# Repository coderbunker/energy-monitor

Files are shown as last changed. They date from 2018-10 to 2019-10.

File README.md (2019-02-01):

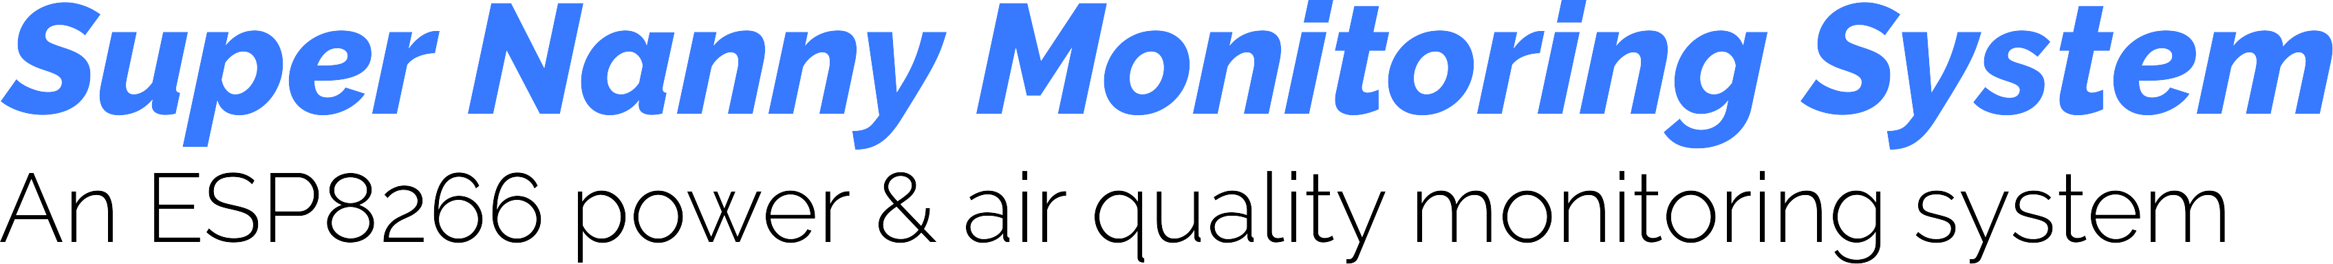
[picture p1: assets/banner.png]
Banner


*Super Nanny Monitory System* is a ESP6288 NodeMCU based monitoring system that measures power consumption and air quality. The MCU collects the data and sends it to the InfluxDB via UDP. 

This is the hardware/firmware repository which contains wiring images, mapping lists and other documentations.

**The Main Programm is [Writing_Database.ino](https://github.com/joelvonrotz/energy-monitor/blob/master/source/Writing_Database/Writing_Database.ino)**

## Measurements Types

The device is split into two devices: power measurement and air quality, so that means double the microcontroller is required instead of a single one.

The two devices can measure power consumption and the air quality as mentioned before. Air quality measurements contains:

- CO2
- TVOC
- Temperature
- Humidity

The power measurement contains the measured power consumption only.

## Setup Arduino

### Arduino IDE

Obviously to use the program in your own version you'd need the Arduino IDE. Simply download it from the Arduino website.
This code has been written with the Arduino language and maybe in the future other options could be available (STM, Atmel, NXP, etc.).

[Link to Arduino IDE](https://www.arduino.cc/en/Main/Software)

### Visual Studio Code Arduino Extension

Faster programmer can use the Arduino extension by Microsoft for Visual Studio Code. Before installing it, be sure to have the Arduino IDE installed, as the extension requires the IDE. It takes some workload off and adds some small nifty features to it.

[Link to extension](https://marketplace.visualstudio.com/items?itemName=vsciot-vscode.vscode-arduino)

### Libraries

To correctly use this program, some libraries need to be installed first. Below should all the needed libraries be listed.

- [InfluxDB-UDP Library](https://github.com/joelvonrotz/Arduino_InfluxDB_UDP) by joelvonrotz
- [Si7021 Library](https://github.com/sparkfun/Si7021_Breakout) by SparkFun
- [CCS811 Library](https://github.com/adafruit/Adafruit_CCS811) by Adafruit
- [ADS1X15 Library](https://github.com/adafruit/Adafruit_ADS1X15) by Adafruit
- [ESP8266 Hardware Package](https://github.com/esp8266/Arduino) by ESP8266.<span></span>com

## Mapping List

The mapping list is used to determine which controller goes into which building and room. First concept was to use a JSON-file in a GitHub repository, but since GitHub is HTTPS secured and using the HTTPS-protocol with the ESP8266 would take a lot of time to learn (time which wasn't available due to our 3-week stay in Shanghai). The problem with HTTPS is the temporary certificates, that lose useability due to their duration. That certificate would need to be refreshed every time the old one is done.

The solution was a hard-coded table, sadly. The MAC address of each ESP is used to get the different information in the table. The advantage of this system is, is that everything is kept offline instead stored in a cloud, which makes offline use kind of useable.

Below is the current mapping since 17th of October 2018.

|MAC Address |Location |Room |Type |
|:---|:---|:---|:---|
| B8:77:10:C2:DD:BC | Building 9  | Fuse box | Power Measurement |
| E8:42:69:3A:7D:80 | Coderbunker | artoffice | Power Measurement |
| FB:61:69:3A:7D:80 | Building 9  | Classroom | Air Quality |
| 49:7A:10:C2:DD:BC | Building 9  | Meeting Room Green | Air Quality |
| CD:36:69:3A:7D:80 | Coderbunker | Art Office | Air Quality |
| 3D:78:10:C2:DD:BC | Coderbunker | Kitchen | Air Quality |

Future people that are going to work on this, please keep this updated if new devices has been integrated into the system.

In the Arduino File called *Writing_Database.ino* is the mapping list and this is how it looks like:

```cpp
const String config[DEVICE_COUNT][TABLE_WIDTH]
{
    //MAC Address          location          room            type
    {"b8:77:10:c2:dd:bc", "building9",      "fusebox",      "power"     },
    {"44:39:69:3a:7d:80", "building1",      "dummy",        "power"     },
    {"e8:42:69:3a:7d:80", "coderbunker",    "artoffice",    "power"     },
    {"cd:36:69:3a:7d:80", "coderbunker",    "kitchen",      "quality"   },
    {"3d:78:10:c2:dd:bc", "coderbunker",    "artoffice",    "quality"   },
    {"fb:61:69:3a:7d:80", "coderbunker",    "classroom",    "quality"   },
    {"49:7a:10:c2:dd:bc", "coderbunker",    "meetingroom",  "quality"   },
    {"49:7a:10:c2:dd:bc", "coderbunker",    "meetingroom",  "quality"   }
};
```

### Add new MCU

To add new devices, it's actually very simple. First upload the program called *Get_MAC.ino* inside the *Get_MAC* folder and then the MAC-Address of the MCU should pop up in the Serial Monitor. Remember it!

Let's say the MAC-Address is ```13:57:91:AB:CD:EF```. Go back to the *Writing_Database.ino* program and increment the definition ```DEVICE_COUNT``` by one, for example from ```7``` to ```8```, so the compiler knows how big the new mapping list is.

If that has been made, let's add the device into the mapping list. Create a new empty package divided into 4 more sections, enough for the MAC-address, location, room and board type.

```cpp
const String config[DEVICE_COUNT][TABLE_WIDTH]
{
    //MAC Address          location          room            type
    {"b8:77:10:c2:dd:bc", "building9",      "fusebox",      "power"     },
    {"44:39:69:3a:7d:80", "building1",      "dummy",        "power"     },
    {"e8:42:69:3a:7d:80", "coderbunker",    "artoffice",    "power"     },
    {"cd:36:69:3a:7d:80", "coderbunker",    "kitchen",      "quality"   },
    {"3d:78:10:c2:dd:bc", "coderbunker",    "artoffice",    "quality"   },
    {"fb:61:69:3a:7d:80", "coderbunker",    "classroom",    "quality"   },
    {"49:7a:10:c2:dd:bc", "coderbunker",    "meetingroom",  "quality"   },
    {                   ,              ,                 ,              }
};
```

Don't forget the comma when adding a new package.

Next step is to fill in the sections. The *first* section is the *MAC-address* with the letters in ***lowercase***. The *second* section is the *location*, as an example let's take ```house``` and for the *third* section, the *room* name, let's take ```livingroom```. The *fourth* section is the *board type* and describes if the board is a power measurement board or an air quality measurement board. In this example it's going to be a power measurement board, so in the fourth section it will say ```power```.

```cpp
const String config[DEVICE_COUNT][TABLE_WIDTH]
{
    //MAC Address          location          room            type
    {"b8:77:10:c2:dd:bc", "building9",      "fusebox",      "power"     },
    {"44:39:69:3a:7d:80", "building1",      "dummy",        "power"     },
    {"e8:42:69:3a:7d:80", "coderbunker",    "artoffice",    "power"     },
    {"cd:36:69:3a:7d:80", "coderbunker",    "kitchen",      "quality"   },
    {"3d:78:10:c2:dd:bc", "coderbunker",    "artoffice",    "quality"   },
    {"fb:61:69:3a:7d:80", "coderbunker",    "classroom",    "quality"   },
    {"49:7a:10:c2:dd:bc", "coderbunker",    "meetingroom",  "quality"   },
    {"13:57:91:ab:cd:ef", "house",          "livingroom" ,  "power"     }
};
```

That's it, the new board is in and when uploading the new program on the MCU, it should configure itself correctly.

### Disadvantage of current solution

The problem with the mapping list is that it's a bad implementation of mapping, but as long as HTTPS is not correctly implemented in the program (updating certificate automatically either doesn't exist or I didn't look good enough in the documentation), it has to be implemented that way.

Additionally the biggest problem is the newer MCU will have a newer firmware with an updated mapping list.

## Sending Data

The current program sends UDP-Packages to a Raspberry Pi, that converts that UDP package to TCP packages and sends them over a HTTPS-connection.

This implementation has only been made to have access to a secure connection to the InfluxDB and it was a lot easier to implement it that way, instead of making our hands dirty to implement SSL on an ESP8266.

## Hardware

### Schematic

#### Air Quality Prototype

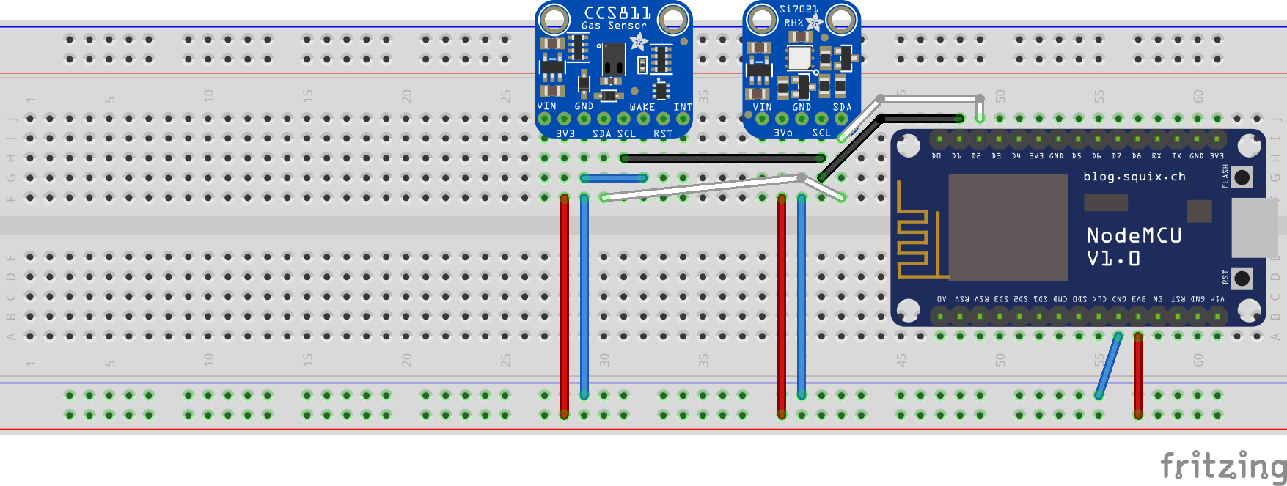
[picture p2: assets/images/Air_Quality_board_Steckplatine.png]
Air Quality Prototype


[PDF of the air quality schematic](assets/pdfs/Air_Quality_board_Schaltplan.pdf)

#### Power Measurement Prototype

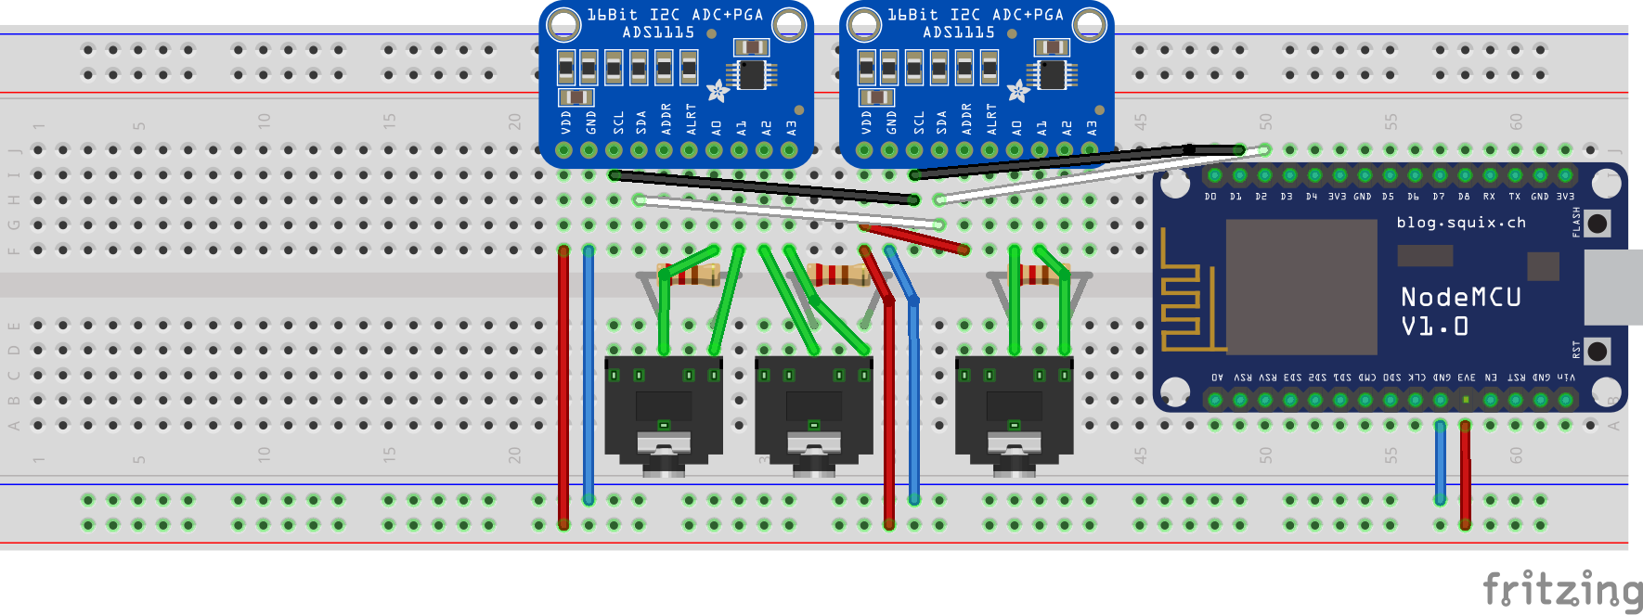
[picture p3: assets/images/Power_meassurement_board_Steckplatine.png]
Power Measurement Prototype


The power measurement doesn't require 2 ADC, this built is for three phase measurements. If only one phase wants to be measured, simply remove the two audio jacks and resistors. The audio jack is a Stereo-jack, that means it has 3 pins: 1 sleeve, 1 ring and 1 tip.

[PDF of the power schematic](assets/pdfs/Power_meassurement_board_Schaltplan.pdf)

### Bill of material

#### Main Components

- ESP8266 NodeMCU v1.0
- USB-Micro cable for programming
- Breadboard or PCB
- Jumper Wires

#### Additional Hardware for Air Quality

- CCS811
- Si7021

#### Additional Hardware for Power Measurement

- ADS1115
- YHDC SCT-013-000 CT Sensor
- 3.5mm Headphone jack to PCB (Stereo or 3 pins)
- Burden Resistor

## Power consumption

### Measurement with test circuit

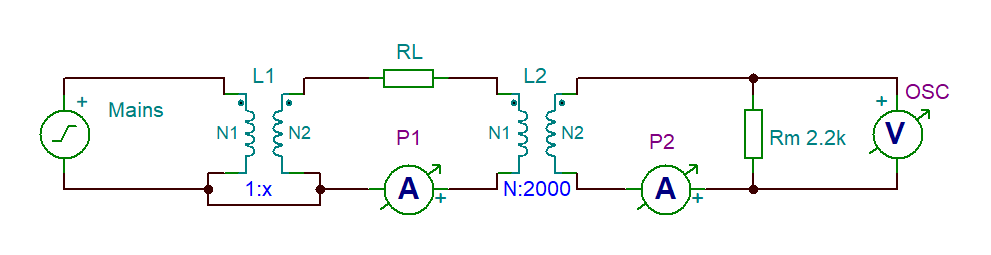
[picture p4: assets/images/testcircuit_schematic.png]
test circuit


**L1 ratio** adjustable

**L2 ratio** 1 : 2000

**P1** UNI-T UT61A

**P2** KAISE MY-60

**OSC** RIGOL DS1054

**L1** DELIXI TDGC2-3KVA

**L2** YHDC SCT013-000-100A-50

---

To check if the circuit actually works, we had to built it up with the stuff that we found at XinCheJian. Fortunately, we found an adjustable transformer and some multimeters. Below should be some measurements we did with two different burden resistors and different currents.

| IP1 | Rm | N | IP2 | IP2\_cal | U1PP  | U1PP\_cal | U1PP\_cal  | IP2/IP2\_cal | U1PP/U1PP\_cal |
|:-----:|:----:|:-----:|:-----:|:---:|:-----:|:---:|:---:|:---:|:---:|
| | | | | | | |based on IP2| | |
| [A] | [Ω]  | [Wdg.]| [mA]  | [mA] | [VPP] | [VPP] | [VPP] | [A/A] | [V/V] |
| 3.045 | 2160 | 1 | 1.130 | 1.523 | 6.680 | 9.300 | 6.900 | 0.740 | 0.720 |
| 2.503 | 2160 | 1 | 0.920 | 1.252 | 5.440 | 7.650 | 5.620 | 0.740 | 0.710 |
| 2.030 | 2160 | 1 | 0.740 | 1.015 | 4.480 | 6.200 | 4.520 | 0.730 | 0.720 |
| 1.503 | 2160 | 1 | 0.560 | 0.752 | 3.370 | 4.590 | 3.420 | 0.750 | 0.730 |
| 1.003 | 2160 | 1 | 0.350 | 0.502 | 2.160 | 3.060 | 2.140 | 0.700 | 0.710 |
| 0.526 | 2160 | 1 | 0.170 | 0.263 | 1.110 | 1.610 | 1.040 | 0.650 | 0.690 |
| 3.166 | 226  | 1 | 1.620 | 1.583 | 1.190 | 1.010 | 1.040 | 1.020 | 1.180 |
| 2.520 | 226  | 1 | 1.280 | 1.260 | 0.872 | 0.810 | 0.820 | 1.020 | 1.080 |
| 2.075 | 226  | 1 | 1.070 | 1.038 | 0.712 | 0.660 | 0.680 | 1.030 | 1.080 |
| 1.580 | 226  | 1 | 0.810 | 0.790 | 0.552 | 0.500 | 0.520 | 1.030 | 1.100 |
| 1.007 | 226  | 1 | 0.510 | 0.504 | 0.352 | 0.320 | 0.330 | 1.010 | 1.100 |
| 0.759 | 226  | 1 | 0.380 | 0.380 | 0.266 | 0.240 | 0.240 | 1.000 | 1.110 |
| 0.539 | 226  | 1 | 0.270 | 0.270 | 0.198 | 0.170 | 0.170 | 1.000 | 1.160 |

The ratio between the currents and voltages are pretty consistent and that's a good sign. The ration only changes when the burden resistor is changed.

### Measurement of three phase cable

Every single wire needs to be measured separately, because of the 120° offset to each other. Measuring all wires together would lead to a total current, which isn't an Addition of all single currents together. Below is able consisting of measurements of each wire.

| Cable ColorThickness | Current IP1 | Voltage U1 (Arduino) | Voltage (UP1\_calc) calculated with current IP1 | Measurement-resistor Rm | Voltage Arduino(U1: UP1\_calc) |
|:---:|:---:|:---:|:---:|:---:|:---:|
| | [A] | [V] | [V] | [Ω] | [V/V] |
| Red thick | 3.920 | 0.493 | 0.443 | 226 | 1.113 |
| Blue thick | 4.750 | 0.577 | 0.537 | 226 | 1.074 |
| Blue thick | 5.280 | 0.640 | 0.597 | 226 | 1.073 |
| Green thick | 2.720 | 0.326 | 0.307 | 226 | 1.060 |
| Red thick | 1.570 | 0.188 | 0.177 | 226 | 1.060 |
| Green thick | 2.850 | 0.333 | 0.322 | 226 | 1.034 |
| Red thin (Neutral) | 4.740 | 0.381 | 0.536 | 226 | 0.712 |
| Red thin (Neutral) | 5.470 | 0.430 | 0.618 | 226 | 0.696 |
| Red thin (Neutral) | 4.370 | 0.312 | 0.494 | 226 | 0.632 |

If you're having trouble with the power measurement or you're not sure if these are the real results, feel free to built it up yourself and update the README if anything else needs to be noted.

### Calculation of burden resistor

The burden resistor is dependent on the size of the mains current. For example, with 220Ω the max current that can be measured is 10A per current transformer.

This chapter contains the needed formula to calculate the burden resistor.

Following values are already known:

***Windings of Current Transformer*** 1 : 2000 |
***Mains Voltage*** 220V<sub>RMS</sub> |
***Max ADC input Voltage*** 6V<sub>PP</sub>

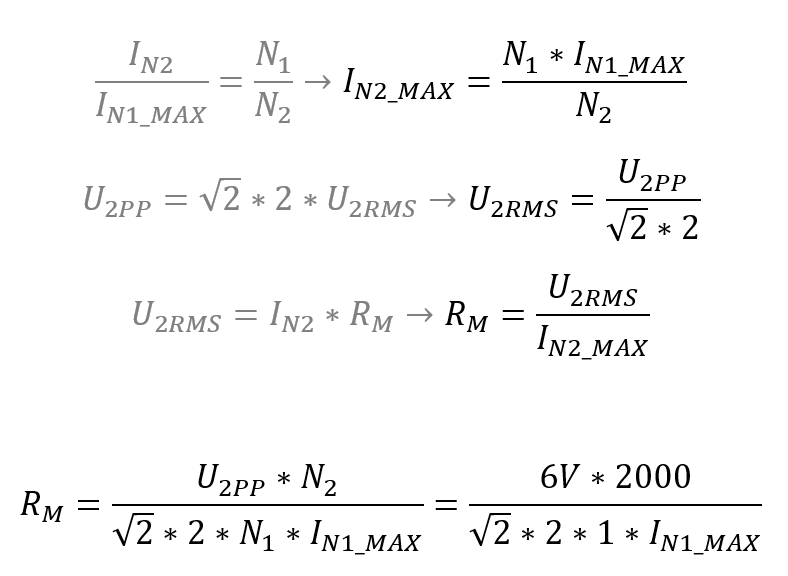
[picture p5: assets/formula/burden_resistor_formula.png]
Formula


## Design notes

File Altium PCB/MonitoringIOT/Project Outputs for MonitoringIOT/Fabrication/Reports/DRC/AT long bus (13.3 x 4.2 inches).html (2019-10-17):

Altium

# Design Rule Verification Report

Date: | | 16.10.2019
Time: | | 10:54:27
Elapsed Time: | | 00:00:00
Filename: | | C:\Users\Lsso\AppData\Local\TempReleases\Snapshot\1\AT long bus (13.3 x 4.2 inches).PCBDOC

Warnings: | | 0
Rule Violations: | | 0

## Summary

Warnings | Count
Total | 0

Rule Violations | Count
Clearance Constraint (Gap=10mil) (All),(All) | 0
Short-Circuit Constraint (Allowed=No) (All),(All) | 0
Un-Routed Net Constraint ( (All) ) | 0
Width Constraint (Min=5mil) (Max=20mil) (Preferred=10mil) (All) | 0
Power Plane Connect Rule(Relief Connect )(Expansion=20mil) (Conductor Width=10mil) (Air Gap=10mil) (Entries=4) (All) | 0
Total | 0

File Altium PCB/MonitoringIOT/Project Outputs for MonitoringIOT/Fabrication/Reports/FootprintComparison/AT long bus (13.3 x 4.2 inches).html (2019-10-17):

Altium customize

# Footprint Comparison Report

Date: | | 16.10.2019
Time: | | 10:54:29
Elapsed Time: | | 00:00:00
Filename: | | C:\Users\Lsso\AppData\Local\TempReleases\Snapshot\1\AT long bus (13.3 x 4.2 inches).PCBDOC

## Contents

Contents

Components Status Summary

Matched Components List

## Components Status Summary

## Matched Components List

Designator | Footprint | Footprint reference | Footprint to reference Library
IC1 | CCS811 | CCS811 | C:\Users\Lsso\AppData\Local\TempReleases\Snapshot\1\PCBlibary.PcbLib
IC2 | ESP8266 | ESP8266 | C:\Users\Lsso\AppData\Local\TempReleases\Snapshot\1\PCBlibary.PcbLib
IC3 | IS7021 | is7021 | C:\Users\Lsso\AppData\Local\TempReleases\Snapshot\1\PCBlibary.PcbLib

Back to top

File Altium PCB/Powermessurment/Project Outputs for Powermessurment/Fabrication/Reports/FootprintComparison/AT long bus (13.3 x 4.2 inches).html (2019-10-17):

Altium customize

# Footprint Comparison Report

Date: | | 11.10.2019
Time: | | 12:41:14
Elapsed Time: | | 00:00:00
Filename: | | C:\Users\Lsso\AppData\Local\TempReleases\Snapshot\1\AT long bus (13.3 x 4.2 inches).PCBDOC

## Contents

Contents

Components Status Summary

Matched Components List

## Components Status Summary

## Matched Components List

Designator | Footprint | Footprint reference | Footprint to reference Library
IC1 | ADS1115 | ADS1115 | C:\Users\Lsso\AppData\Local\TempReleases\Snapshot\1\PCBlibary.PcbLib
IC2 | ESP8266 | ESP8266 | C:\Users\Lsso\AppData\Local\TempReleases\Snapshot\1\PCBlibary.PcbLib
IC3 | ADS1115 | ADS1115 | C:\Users\Lsso\AppData\Local\TempReleases\Snapshot\1\PCBlibary.PcbLib
J1 | 3,5mm Jack | 3,5mm Jack | C:\Users\Lsso\AppData\Local\TempReleases\Snapshot\1\PCBlibary.PcbLib
J2 | 3,5mm Jack | 3,5mm Jack | C:\Users\Lsso\AppData\Local\TempReleases\Snapshot\1\PCBlibary.PcbLib
J3 | 3,5mm Jack | 3,5mm Jack | C:\Users\Lsso\AppData\Local\TempReleases\Snapshot\1\PCBlibary.PcbLib
R3 | 220E | 220E | C:\Users\Lsso\AppData\Local\TempReleases\Snapshot\1\PCBlibary.PcbLib
R4 | 220E | 220E | C:\Users\Lsso\AppData\Local\TempReleases\Snapshot\1\PCBlibary.PcbLib
R5 | 220E | 220E | C:\Users\Lsso\AppData\Local\TempReleases\Snapshot\1\PCBlibary.PcbLib

Back to top

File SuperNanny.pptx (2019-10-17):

## SuperNanny

ICT Project
Simon, Ismail, Ibish, Anna

## Contents

- What has been achieved
- Demonstration
- Challenges
- Improvement for the next time

## What has been achieved

- A fully functional power monitoring system where
- An environment monitoring system where you can receive the configuration from the cloud and monitor CO2, TVOC, Temperature and Humidity. Everything works but the CO2 Sensor is drifting after several hours.

## Power measurement

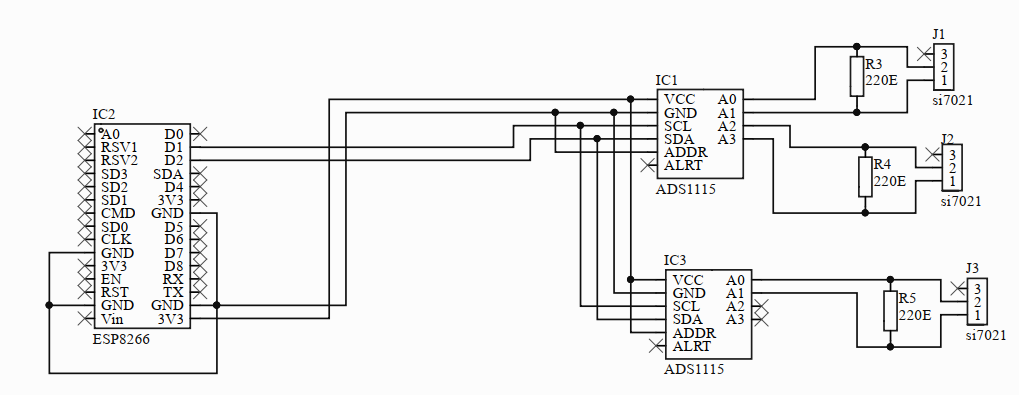
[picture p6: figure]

## Power measurement

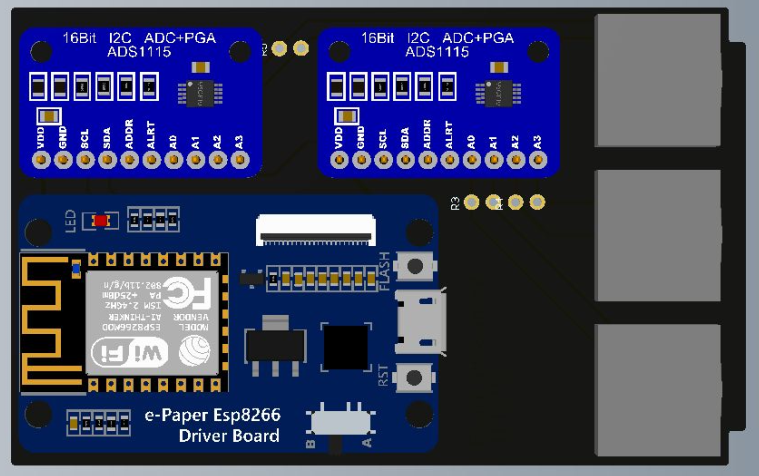
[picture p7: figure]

## Power measurement

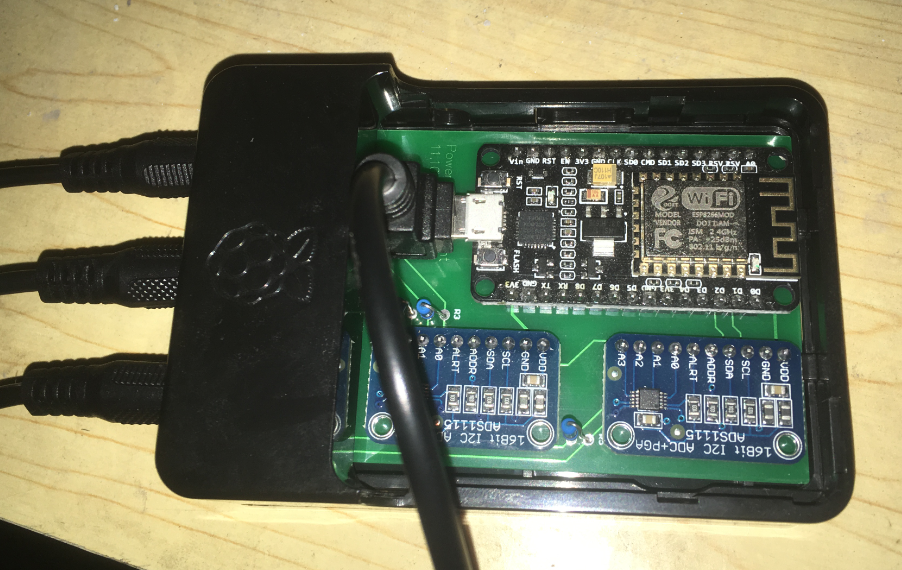
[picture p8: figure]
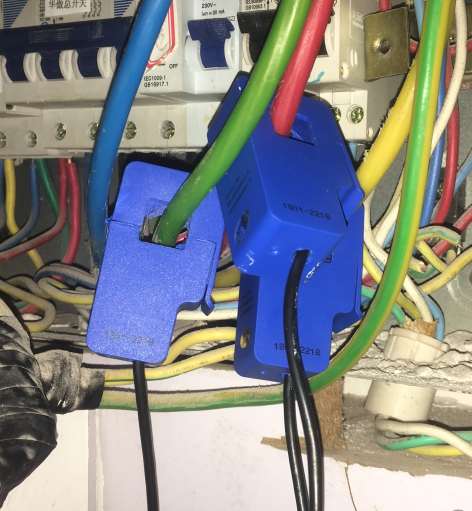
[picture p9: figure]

## Environment measurement

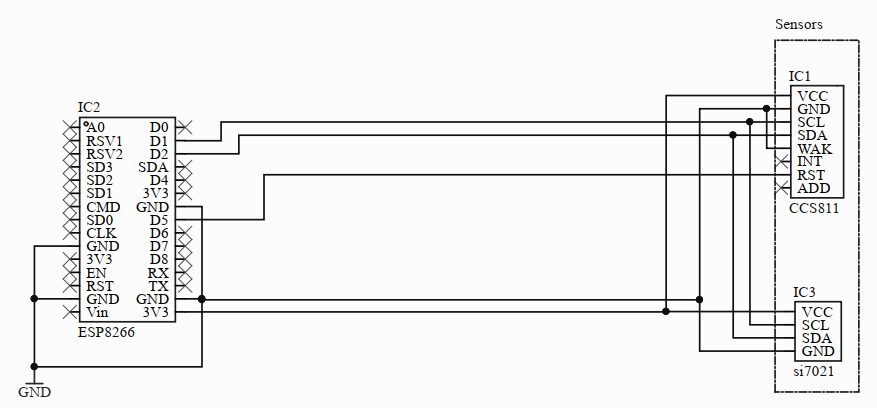
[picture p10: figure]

## Environment measurement

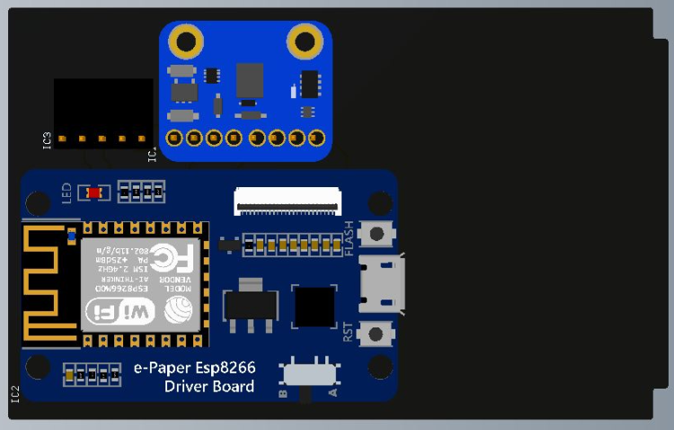
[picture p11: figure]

## Demonstration

Power measurement in Chronograpf
https://chronograf01.monitor.agora-space.com/sources/1/dashboards/20?lower=now%28%29%20-%205m

## Challenges

- Sensor
- Network
- Communication
- Environment and equipment
- Communication with configuration API and Arduino

## Improve for the next time

- Better communication with the project owner, say him more clearly what we want and need and get the information out from him what he wants from as.
- Take an other sensor, that hasn’t the problem with the drifting

## Questions

?

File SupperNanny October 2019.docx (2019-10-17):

SuperNanny October 2019 (SuperNanny V2)
Documentation

Electronic: Simon, Anna; Computer science: Ismail, Ibish

Project goal:
We had to make a working monitoring system, that could be produced cheap and by large numbers. It should monitor the air quality, CO2 content, temperature and the humidity.

Starting position:
There was already a part of the monitoring hardware available. We had to get those components to work properly and make a hardware that include everything. That we have just one gadget at the end. So, it would be quite practical, you just have to plug in one devise, and it’s done. You would be able to look at all the data’s in a cloud.

Hardware:

We had to make some chances in the Wifi-connection. In the beginning there was only a connection from the Arduino to the cloud and it should actually by a communication from the Arduino to the Pi and afterword’s to the cloud.

There was also a problem in the Wifi-connection it wasn’t working as it should have. They had to be done some changes in the program that it was able to work.

The air quality and CO2 content sensor were drifting after some time in use. We let the sensor reset every 20min to prevent it from drifting but there was the problem that the sensor needs 20min to warm up to give useable data. We have to find the problem. The problem could be produced by many different factors. We ordered new sensors to be sure that the sensors aren’t damaged from ESD or other sings. And we made PCBs to be sure that the wrong data is not produced from the scratchboard. You can’t order 2 PCBs, no we had to order 45 PCBs, and they will arrive on the second last day. And the ordered sensors we can’t really test because we don’t have any ESD protection. We thought that Nelson would have something, but he doesn’t, so we had to order them to.
The ESD protection arrived and the PCBs to, so we could make the power masurement

The power management hardware and software were working. There was only the problem that the wrong data was showed in the Grapf.

There was no scheme that included everything, there were not even subschemas of everything. So, we design one that included everything to in order to provide clarity.

Other problems:
We had, in the beginning’s, problems with the communication between our team and the project owner. He never really gave as requirements of the project. And he often changed his mind about things, as if he doesn’t really know by himself what he wants. We discussed this with him to make a change that sings work the right way as they should, but he explained that he don’t want to have a final project as it was said, no he wants as to learn how it is to work in a start-up.
There was also a problem with the equipment, we hadn’t really had any electronic equipment to make the electronic stuff, and if they had something it took always a long time to get them.

Product:
Two different products: Power measurements and monitoring system.
The Power measurement is working with no problem on the scratchboard, so we made a PCB that would fit in a Raspberry Pi case. It is working perfectly fine.
An environment monitoring system where you can receive the configuration from the cloud and monitor CO2, TVOC, Temperature and Humidity. Everything works but the CO2 Sensor is drifting after several hours. And because of this we didn’t produced this PCB, we still have the scheme and a finished layout.

Stocklist:
In the stocklist are all the components listed.

Code:
Writhing_Database is the program to upload on the Arduinos.

Scheme:

Power measurement:

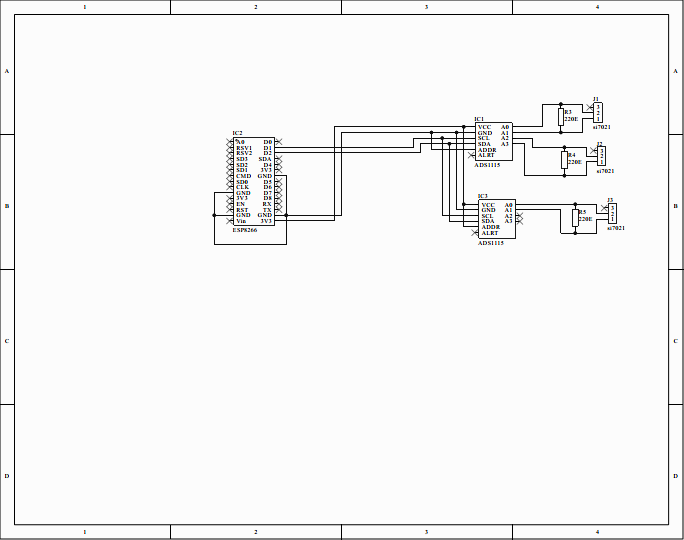
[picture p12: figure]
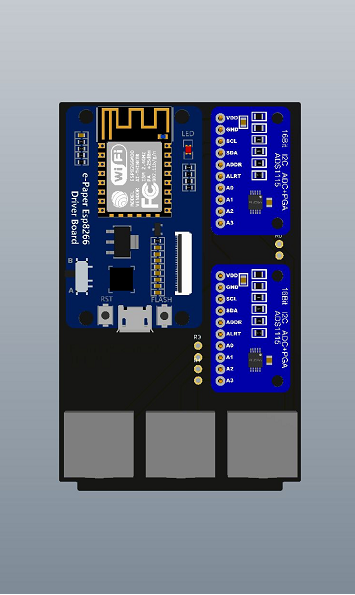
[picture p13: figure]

Environment monitoring

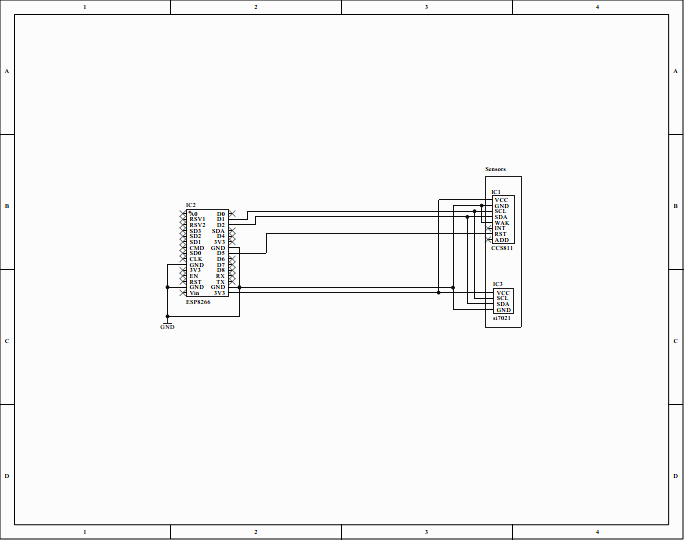
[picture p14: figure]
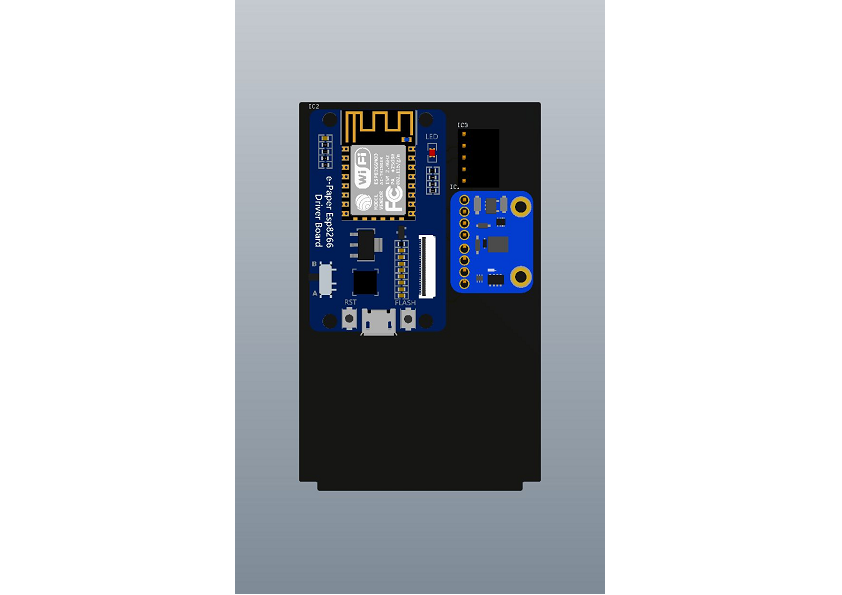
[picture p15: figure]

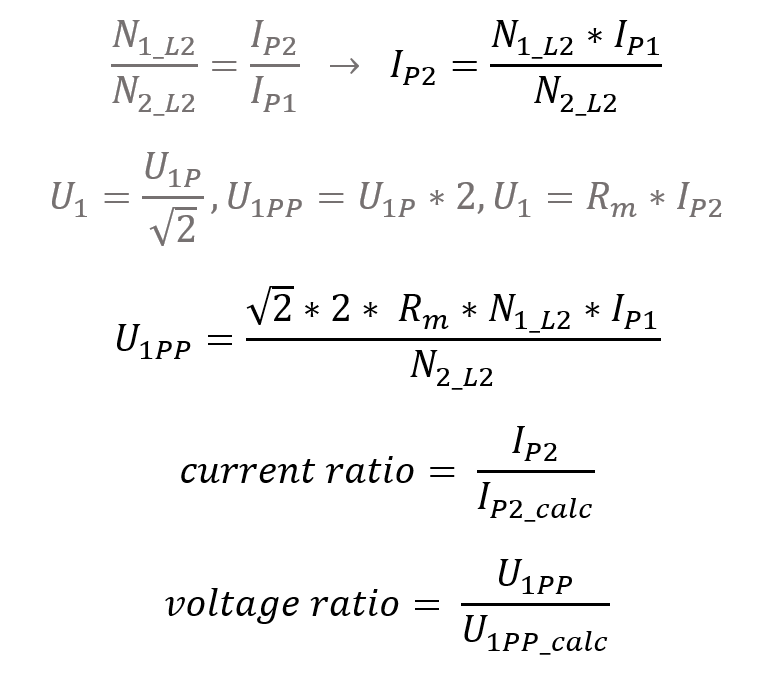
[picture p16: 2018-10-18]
assets/formula/formula_calculation.png

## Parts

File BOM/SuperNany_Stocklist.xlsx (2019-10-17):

Stocklist
SuperNanny V2
2019 Oktober
Simon, Ismail, Ibish, Anna
There aren’t that reliable suppliers in China. So, try to by the same thing we bought, we looked for components on Alibaba because it was the only thing we know.
BOM | Environmental conditions
Typ | Cost / piec | supplyer | supplyer link | min order | Amount
si7021 | 0,3571 | Alibaba | https://german.alibaba.com/product-detail/Humidity-Sensor-with-I2C-Interface-Si7021-60756946240.html | 1 | 1
ccs811 | 0,0715 - 25 | Alibaba | https://german.alibaba.com/product-detail/NEW-CCS811-SI7021-BMP280-Carbon-Dioxide-62101063980.html | 1 | 1
ESP8266 NodeMCU v1.0 | 1,4 - 14 | Alibaba | https://german.alibaba.com/product-detail/YIKESHU-Best-quality-New-and-original-62010089121.html?s=p | 10 | 1
Micro SD Card Module | 2.86-5.72 | Alibaba | https://www.alibaba.com/product-detail/Micro-SD-Card-Module-TF-Card_60673442175.html | 10 | 1
Raspberry Pi 3 Case | 29.91-32.05 | Alibaba | https://www.alibaba.com/product-detail/Raspberry-Pi-3-Case-Can-Work_60762114166.html | 1 | 1
Total Cost: | 80 | CNY
BOM | Power Measurement
Typ | Cost / piec | supplyer | supplyer link | min order
Audio jack | 0.0715-70.44 | Alibaba | https://german.alibaba.com/product-detail/5-pin-3-5mm-audio-jack-socket-pcb-panel-mount-for-headphone-pcb-mount-stereo-jack-62094653298.html | 1 | 3
ESP8266 NodeMCU v1.0 | 1,4 - 14 | Alibaba | https://german.alibaba.com/product-detail/YIKESHU-Best-quality-New-and-original-62010089121.html?s=p | 10 | 1
ADS1115 | 10,36 | Alibaba | https://german.alibaba.com/product-detail/16-Bit-I2C-4-channel-ADC-62249733834.html | 10 | 3
100A SCT-013-000 | 7 | Alibaba | https://german.alibaba.com/product-detail/Hot-selling-Non-invasive-Split-Core-62126798652.html | 1 | 3
Resistor | 1 | Alibaba |  | 10
Micro SD Card Module | 2.86-5.72 | Alibaba | https://www.alibaba.com/product-detail/Micro-SD-Card-Module-TF-Card_60673442175.html | 10 | 1
Total Cost: | 110 | CNY
si7021 | ccs811 |  |  | ESP8266 NodeMCU v1.0 |  | Micro SD Card Module | Raspberry Pi 3 Case | ADS1115 | 100A SCT-013-000 | Audio jack

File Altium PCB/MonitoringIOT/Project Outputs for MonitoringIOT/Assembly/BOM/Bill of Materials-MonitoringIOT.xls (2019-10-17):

Comment | Description | Designator | Footprint | LibRef | Quantity
CCS811 |  | IC1 | CCS811 | CCS811 | 1
ESP8266 |  | IC2 | ESP8266 | ESP8266 | 1
si7021 |  | IC3 | is7021 | si7021 | 1

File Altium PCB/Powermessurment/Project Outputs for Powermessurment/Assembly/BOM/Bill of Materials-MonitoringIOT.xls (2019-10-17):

Comment | Description | Designator | Footprint | LibRef | Quantity
ADS1115 |  | IC1, IC3 | ADS1115 | ADS1115 | 2
ESP8266 |  | IC2 | ESP8266 | ESP8266 | 1
si7021 |  | J1, J2, J3 | 3,5mm Jack | 3,5mm Jack | 3
220E |  | R3, R4, R5 | 220E | 220E | 3

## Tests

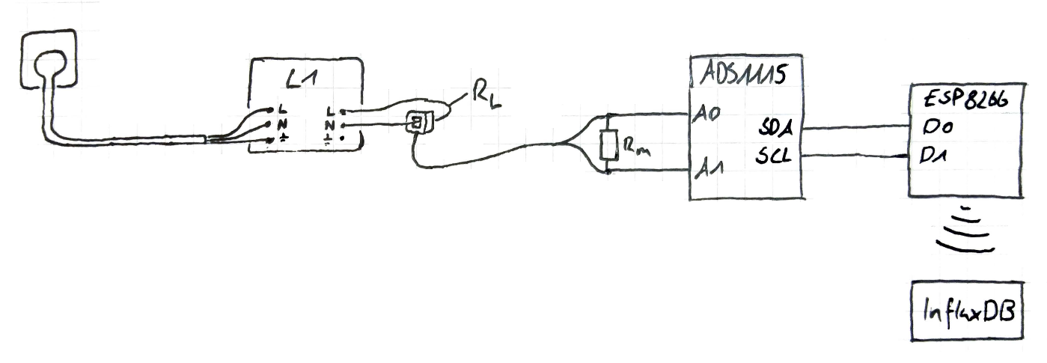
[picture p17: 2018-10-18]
assets/images/10a_measurement.png

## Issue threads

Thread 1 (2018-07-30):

Run correctly with influxdb

limace11, 2018-07-30:
Need to find a good way for the udp part with influxdb

Test now with :  "ESPinfluxdb.h" library

lenzai, 2018-07-30:
I was not aware of any issue communicating with influxdb on previous deployment. Are you trying to run a different configuration?

limace11, 2018-07-31:
the initial target of the project is without grafana.
But for use grafana is better with a good data synthesis, and this is possible with this library.

The UDP communication is

power : xxx
power : xxx

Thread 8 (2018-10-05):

Debug HW for messuring electronics

BigGold1310, 2018-10-05:
FIX the wrong power consumption measurement

- [x] Circuit analysis of electronic construction
- [x] Redimension hardware to get stable, useable signal on Measurement-Resistor
- [x] Comission ADC+Eval Board: System measures Current consumption correct.
- [x] Test hardware on air conditioner
- [x] Finish Documentation on Debugging Hardware

joelvonrotz, 2018-10-05:
- [x] Measure voltage on measurement-reistor
- [x] Calculate ratio out of measured voltage & current and calculated voltage & current
- [ ] Test hardware on air conditioner

joelvonrotz, 2018-10-05:
- [x] Measure voltage on measurement-reistor
- [x] Calculate ratio out of measured voltage & current and calculated voltage & current
- [ ] Test hardware on air conditioner

codebru, 2018-12-05:
@joelvonrotz @BigGold1310 by the comments I assume this is done and will close.

Closed 2018-12-05.

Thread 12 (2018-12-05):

Air quality monitor drift

codebru, 2018-12-05:
Air quality monitors CO2 and VOC are drifting after 5-10 hours of operation.

codebru, 2018-12-05:
@lenzai
Baylin has send the parts now so when they get to the UK I will prototype the circuit and reproduce the issue. My current instinct is to simply have a transistor that switches the sensor off momentarily. What is your targeted frequency for the data?

lenzai, 2019-10-07:
put 4 devices in the same location. 2/4 sensors are drifting:
- classroom
- artoffice
https://chronograf01.monitor.agora-space.com/sources/1/dashboards/12?lower=now%28%29%20-%202d

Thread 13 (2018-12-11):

Finalise Circuit Design

codebru, 2018-12-11:
# Background
Before we can address https://github.com/coderbunker/energy-monitor/issues/10 we need to finalise the circuit designs and have some kind of release system for those so more can go into deployment.

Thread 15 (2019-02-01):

Intermittent functionality of both sensors running on the same pins

codebru, 2019-02-01:
# Issue
I have have intermittent issues running the sensors on the same pins (bus).  In simple terms, if both sensors run off D1 & D2 neither give a coherent output. I have managed to get it to work in my home prototype but this needs to be reviewed - hence intermittent.

# Debug Information
_Pending_

---
Note: Apologies for the not very fleshed out ticket I still need to dig more in to this, I just didn't want it to be forgotten.

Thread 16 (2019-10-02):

fix arduino device #2 for electricity monitoring in bunker ( 1 phase is measuring 0)

Lotok, 2019-10-02:

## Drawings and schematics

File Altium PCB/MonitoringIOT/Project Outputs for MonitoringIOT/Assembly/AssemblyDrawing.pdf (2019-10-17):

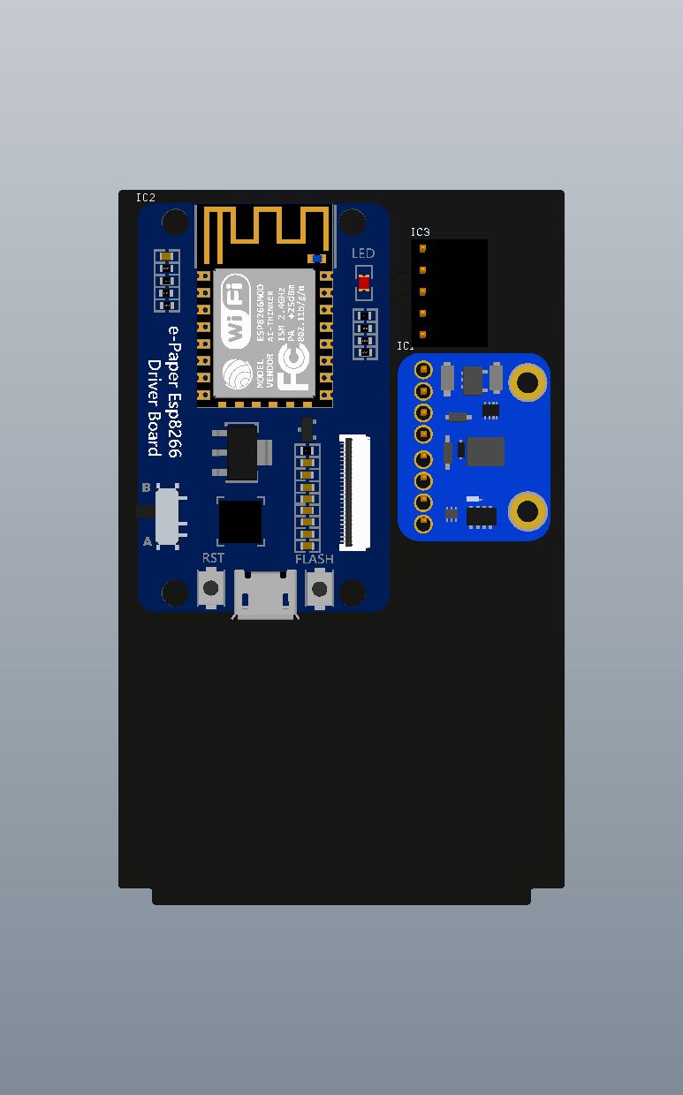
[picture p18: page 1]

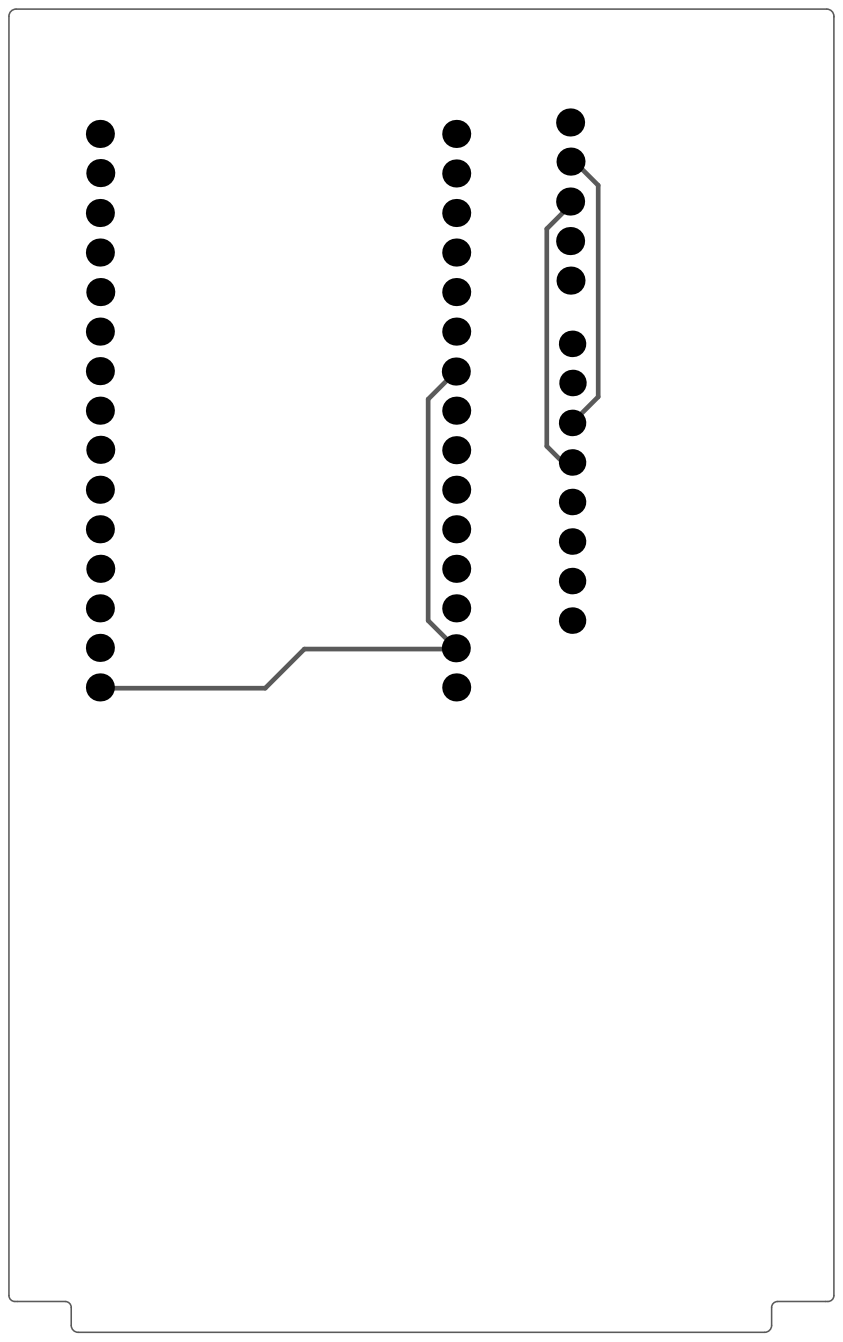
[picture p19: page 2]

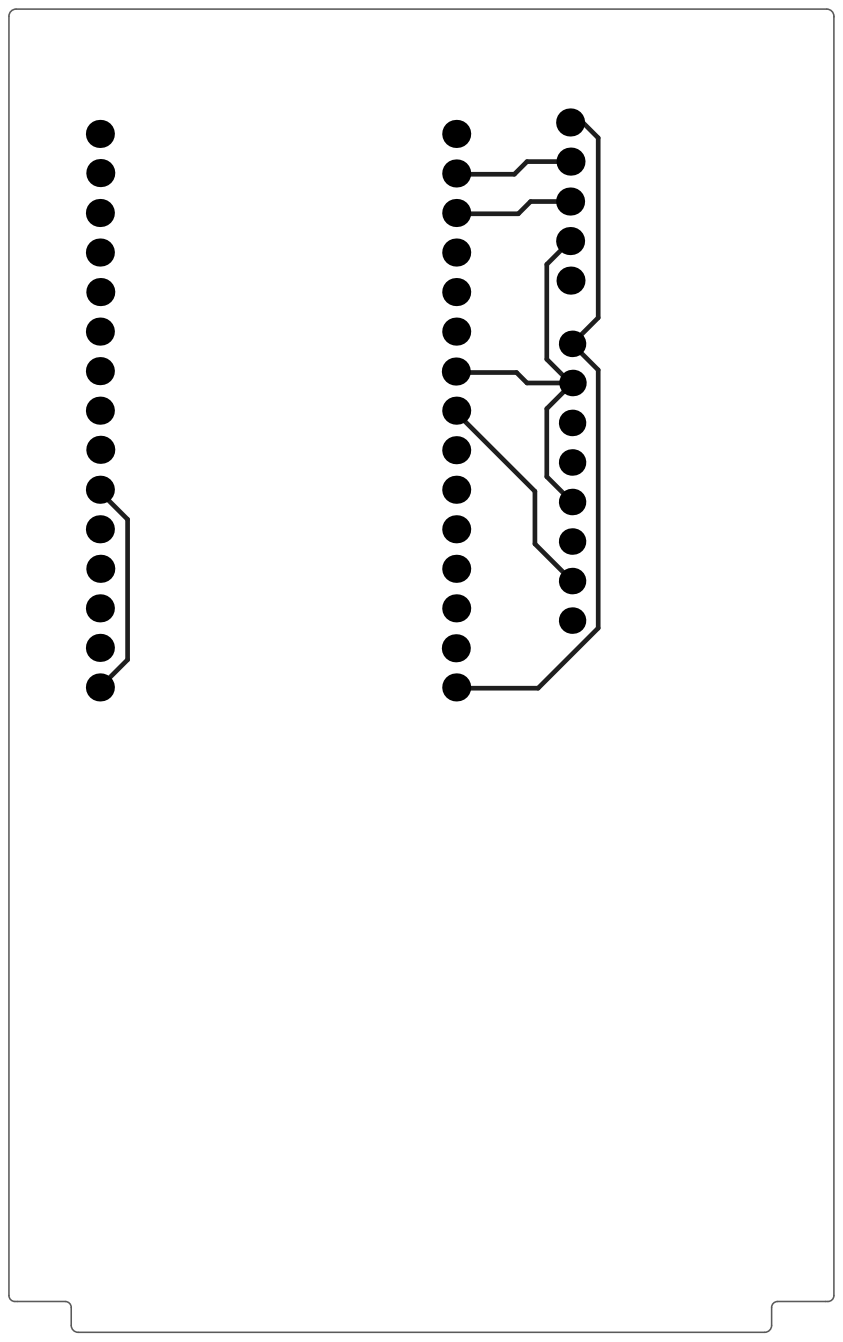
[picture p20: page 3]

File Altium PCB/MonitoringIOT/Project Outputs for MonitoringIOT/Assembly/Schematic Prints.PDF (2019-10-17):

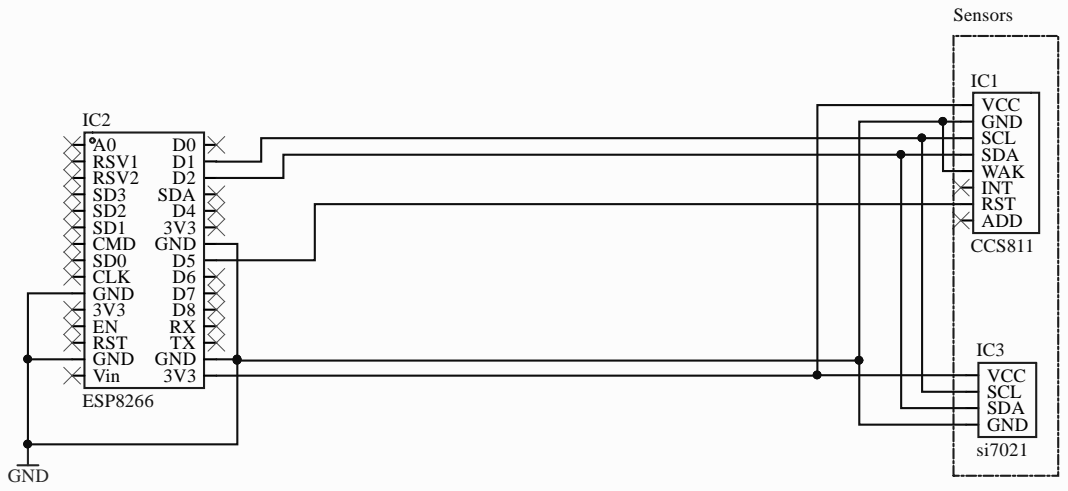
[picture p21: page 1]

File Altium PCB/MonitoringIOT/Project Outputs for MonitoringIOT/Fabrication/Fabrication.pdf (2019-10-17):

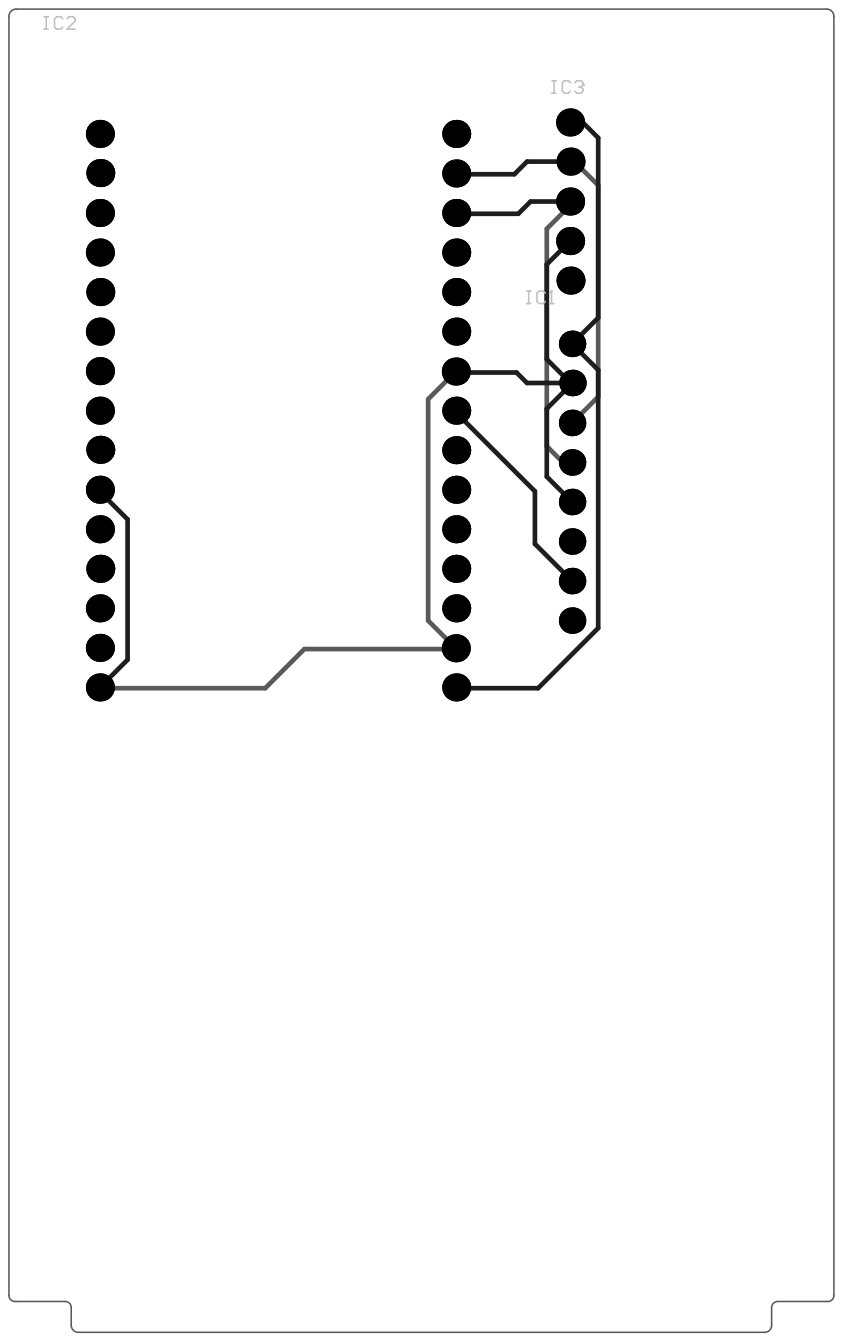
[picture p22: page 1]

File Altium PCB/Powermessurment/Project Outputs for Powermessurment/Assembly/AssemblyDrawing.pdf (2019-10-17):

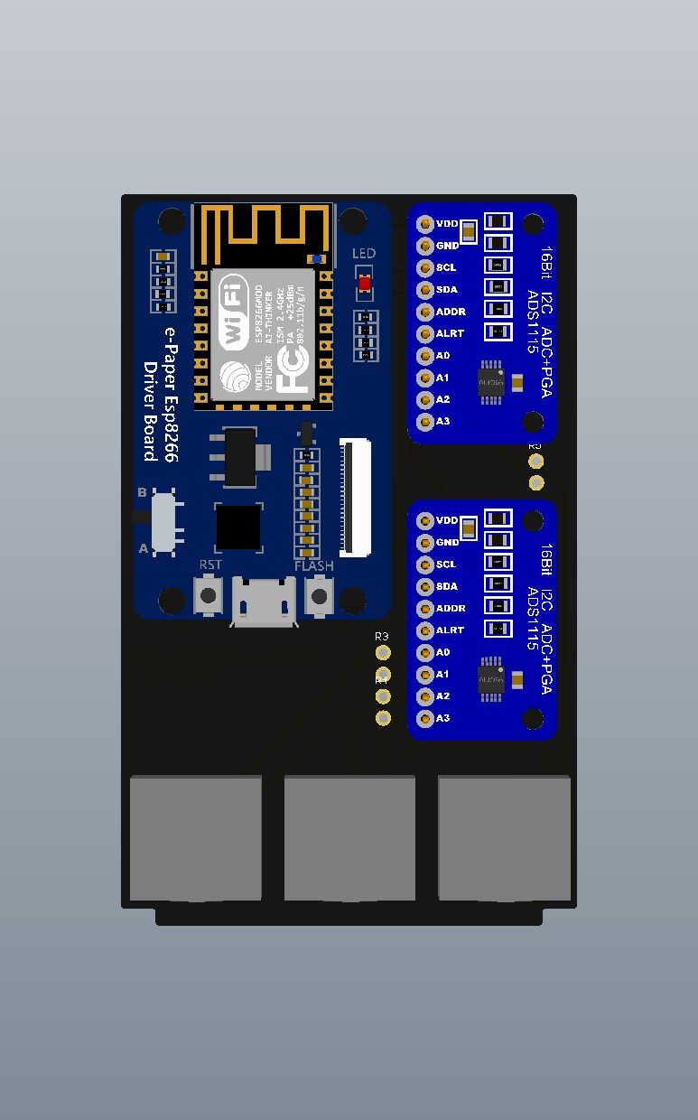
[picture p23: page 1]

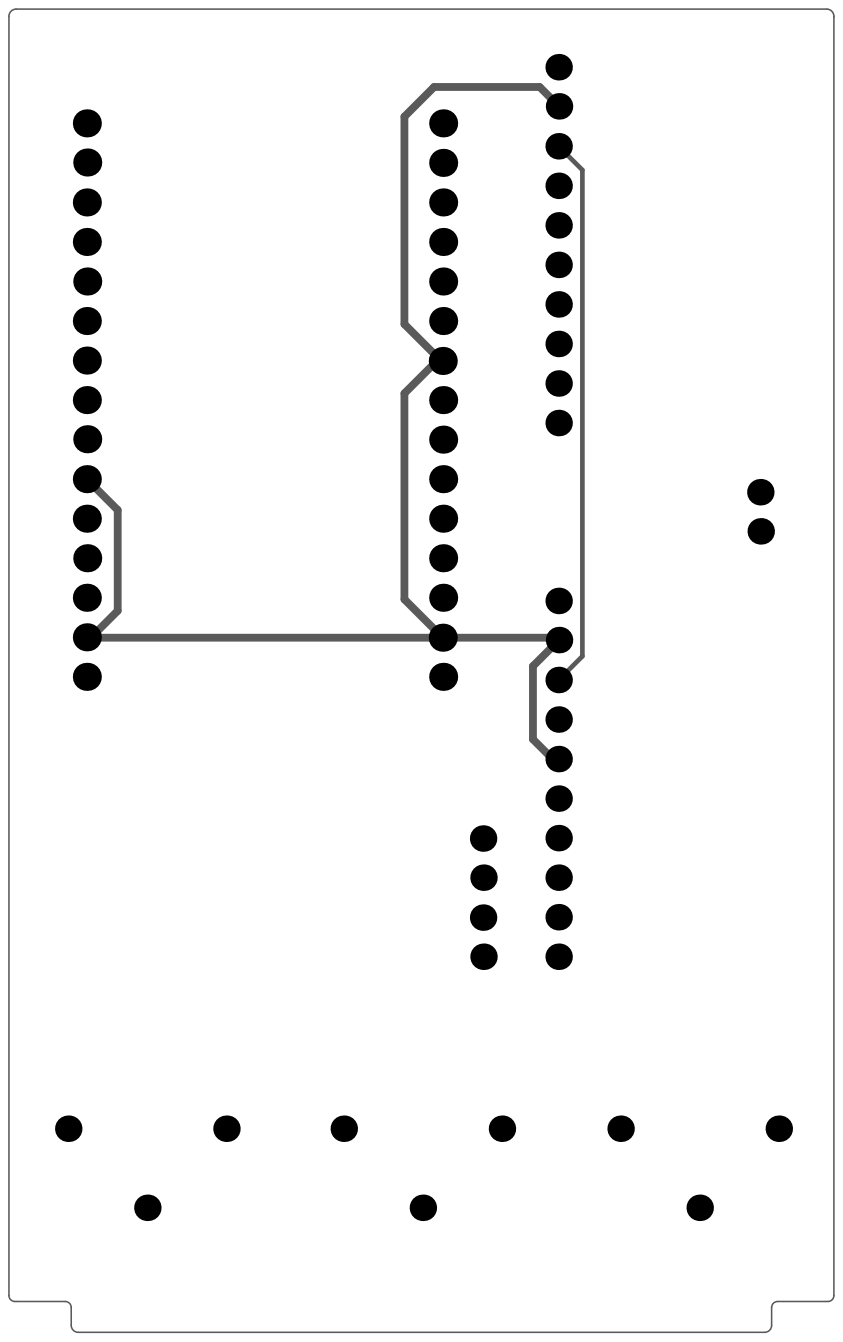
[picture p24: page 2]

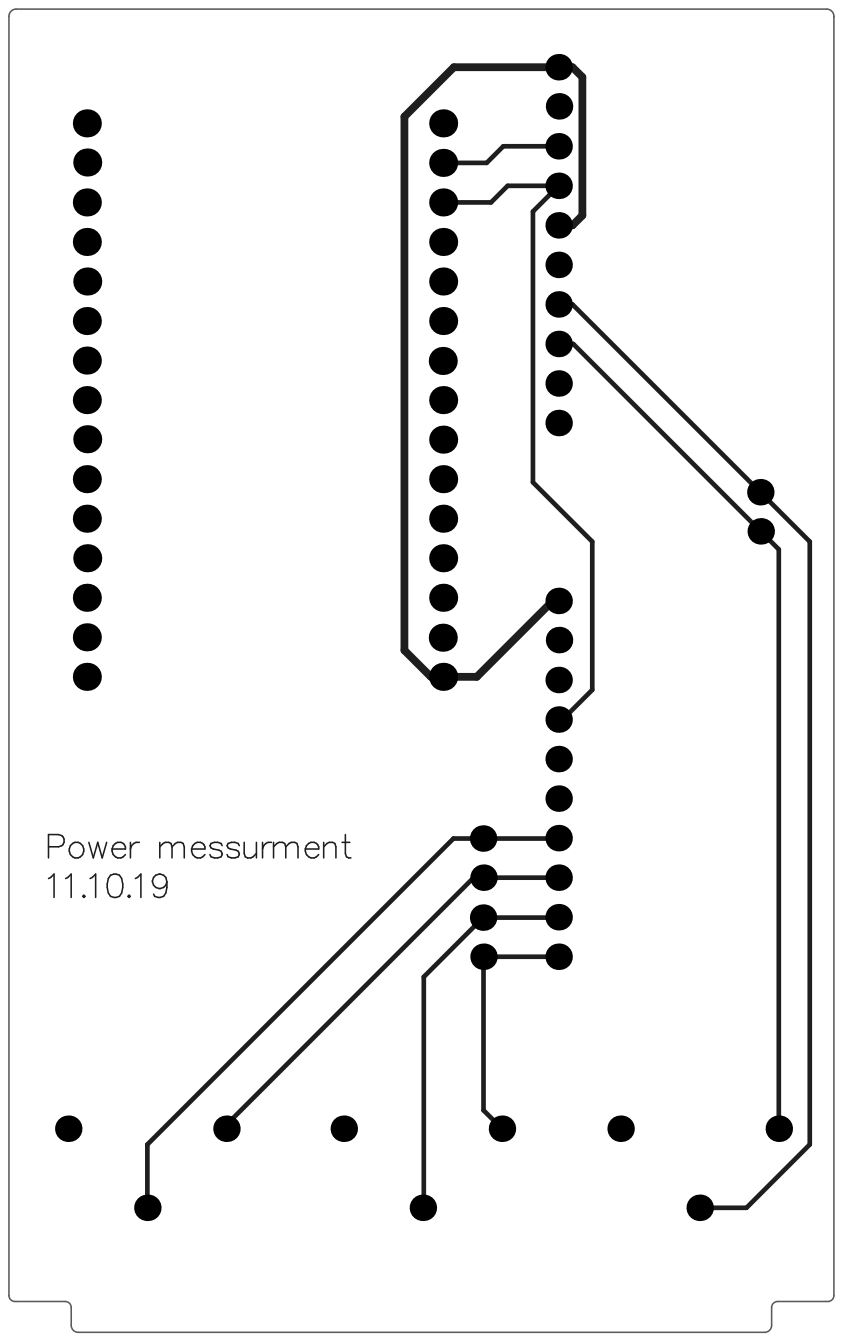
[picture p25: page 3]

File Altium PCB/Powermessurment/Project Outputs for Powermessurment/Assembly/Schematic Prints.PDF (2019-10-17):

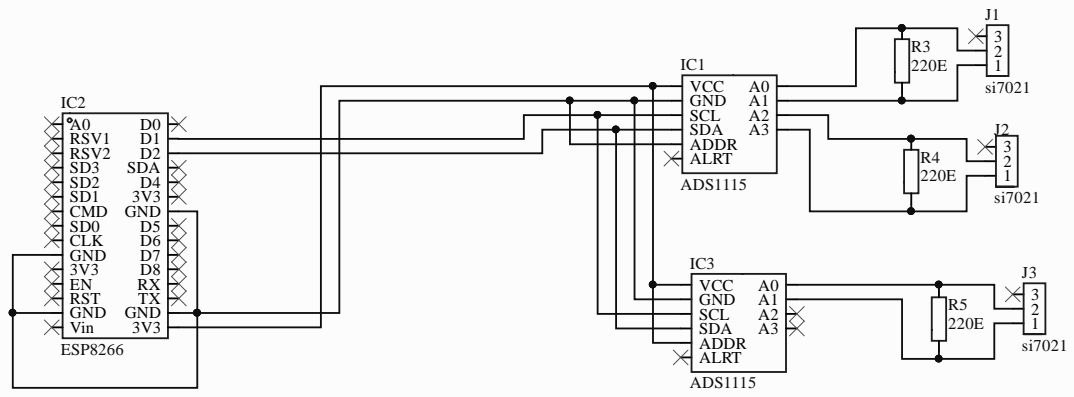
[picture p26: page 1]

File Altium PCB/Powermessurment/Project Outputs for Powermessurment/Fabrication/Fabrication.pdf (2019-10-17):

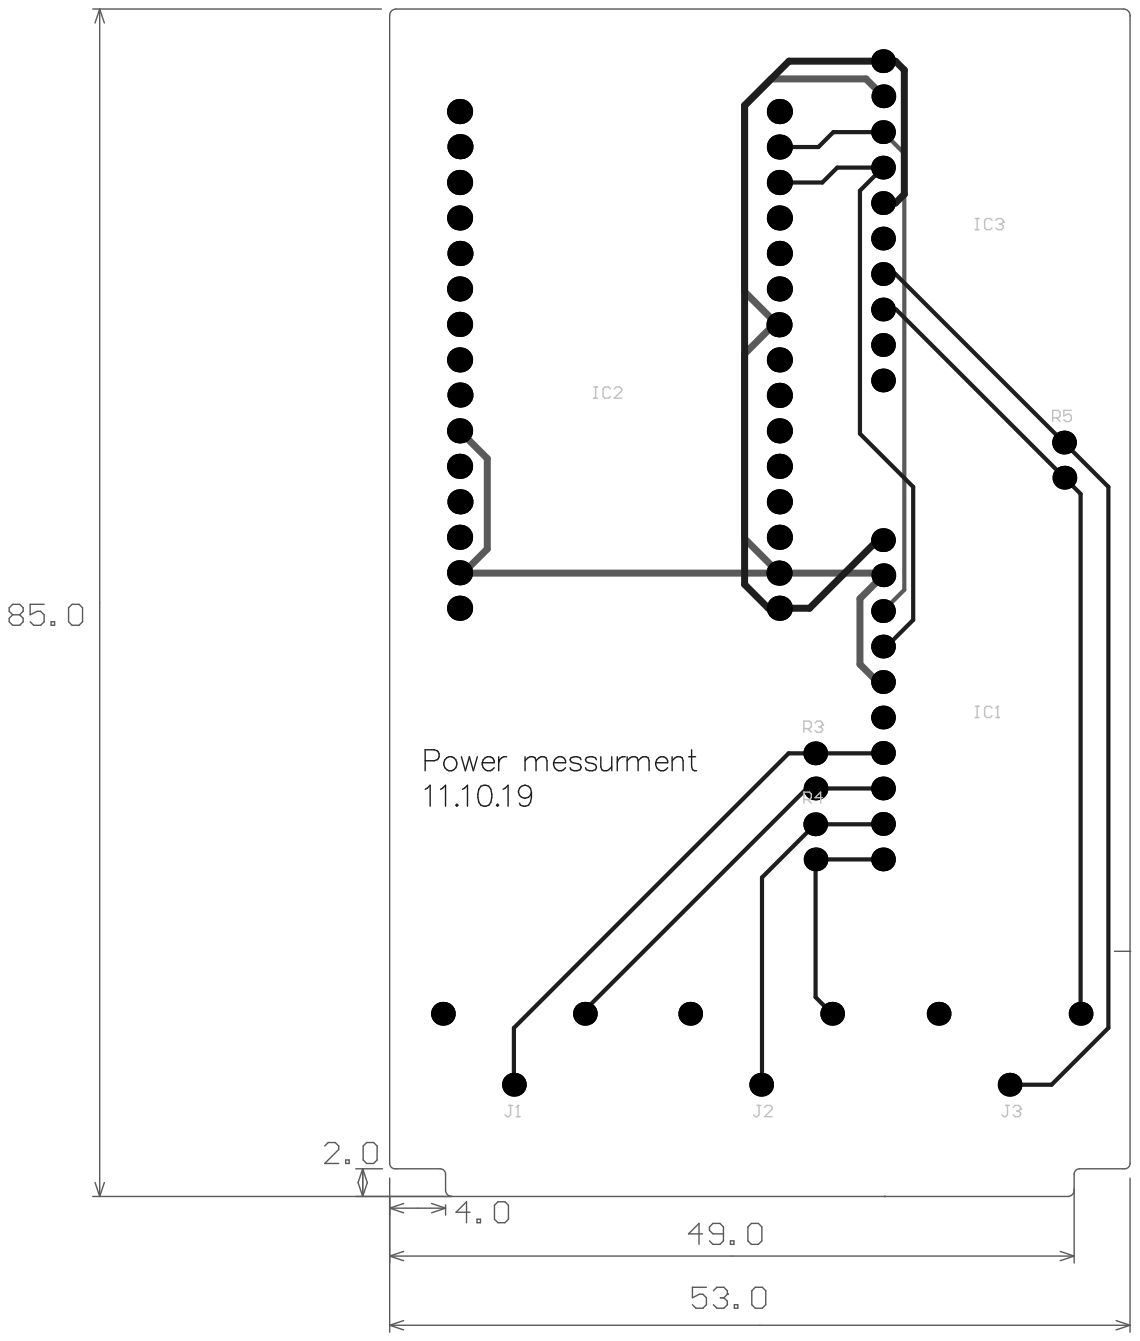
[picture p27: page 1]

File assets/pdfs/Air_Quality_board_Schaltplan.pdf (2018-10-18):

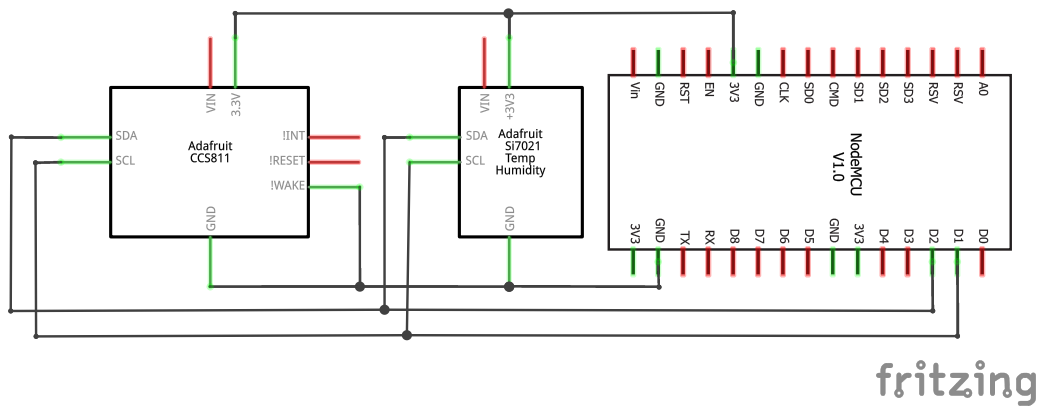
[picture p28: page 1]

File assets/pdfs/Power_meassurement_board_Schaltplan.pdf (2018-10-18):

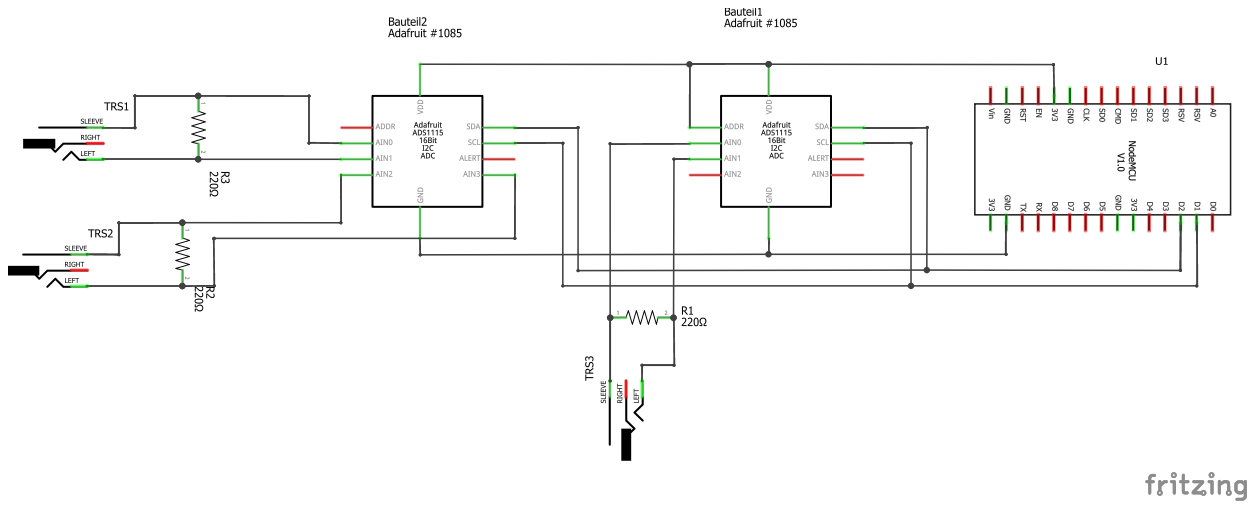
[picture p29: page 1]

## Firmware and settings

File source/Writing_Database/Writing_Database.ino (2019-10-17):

//WiFi
#include <ESP8266WiFi.h>
#include <WiFiUdp.h>

//InfluxDB
#include <influxDB_udp.h>

//Utility
#include <string.h>
#include <math.h>
#include <Ticker.h>

//Sensor Library
#include <Wire.h>
#include <Adafruit_ADS1015.h>
#include <SparkFun_Si7021_Breakout_Library.h>
#include <Adafruit_CCS811.h>

// HTTP
#include <Bridge.h>
#include <HttpClient.h>

// JSON
#include <ArduinoJson.h>

//-----------------------------------------------------------------------------
#define DEVICE_VERSION 0.9
#define DEVICE_COUNT 7

#define TABLE_HEIGHT DEVICE_COUNT
#define TABLE_WIDTH 4

#define INDEX_MAC 0
#define INDEX_LOCATION 1
#define INDEX_ROOM 2
#define INDEX_TYPE 3
#define INDEX_Offset 4

#define SparkFun_Si7021 Weather

//SHA1 finger print of certificate use web browser to view and copy
const char fingerprint[] PROGMEM = "11e76ce84e2d03e19a9a65f925e0d9b15bc1e76c";

//WiFi Information -- START ---------------------------------------------------
String config_host = "chronograf01.monitor.agora-space.com";

const char *ssid = "Agora Space";
const char *password = "getstuffdone";

bool isPowerType;
bool isQualityType;

String MacToString(const uint8_t *mac);

//InfluxDB initialisation -- START --------------------------------------------
WiFiUDP udp;
InfluxDB_Data dataPower("power_measurement");
InfluxDB_Data dataAirQuality("quality_measurement");
//InfluxDB initialisation -- END ----------------------------------------------

//Ticker stuff -- START -------------------------------------------------------
Ticker DB_Updater;
int Timer = 0;
bool tickOccured = false;

void timerCallback()
{
    tickOccured = true;
    if (Timer >= 50)
    {
        Timer = 0;
        getConfigFromPi();
    }
    else
    {
        Timer++;
    }
}
//Ticker stuff -- UDP ---------------------------------------------------------

Adafruit_ADS1115 ADC_1(0x49); //Create ADS1115 object
Adafruit_ADS1115 ADC_2(0x48); //Create ADS1115 object
SparkFun_Si7021 Si7021;       //Create Instance of Si7021 temperature and humidity sensor
Adafruit_CCS811 CCS811;       //Create CCS811 object

const float SCALEFACTOR = 0.125F;   // This is the scale factor for the default +/- 4.096V Range we will use - see ADS1X15 Library
const float BURDEN_RESISTOR = 220;  // Burden resistor where measurement voltage gets measured.
const float VOLTAGE_MAINS = 220.00; // line voltage
const float COIL_WINDING = 2000;    // ratio of sensor 100:0.05

//int16_t rawADCvalue;  // The is where we store the value we receive from the ADS1115
float MAX_CURRENT_COIL = 0.0707; // Maximum current of sensor rated at  Rms 100 A
float MAX_VOLTAGE_ADC = 15.981;  // Maximum Voltage on burden resistor calculated by burden resistor * maxAmps (33 Ohm * 0.0707 A)

float voltage_adc_1 = 0.0; // The result of applying the scale factor to the raw value
float voltage_adc_2 = 0.0;
float voltage_adc_3 = 0.0;

float current_coil = 0.0; // Calculated depending on the Voltage/Burden resistor

float power_1 = 0.0;
float power_2 = 0.0;
float power_3 = 0.0;
float power_total = 0.0;

float humidity = 0;
float temperature = 0;

float eCO2 = 0;
float TVOC = 0;
float eCO2OLD = 0;
float TVOCOLD = 0;
float LongRST = 0;

int writeflag = 0;
int Powerflag = 0;

String line;
String PowerAsString;

int n = 0;

class ArduinoConfig
{
public:
    String location = "";
    String influx_bd_host = "";
    String room = "";
    String mac = "";
    String sensor_type = "";
    int quality_port = 0;
    int power_port = 0;
    int offset_temperature = 0;
    int offset_humidity = 0;
};

ArduinoConfig *arduinoConfig;

void SWI(void)
{
    writeflag = 0;
    digitalWrite(D5, LOW); //Reset Sensor
    delay(100);
    digitalWrite(D5, HIGH);
    Serial.println("Reset Sensor");
    CCS811.begin();
    delay(5000);
    while (eCO2 == 0.00)
    {
        eCO2 = CCS811.geteCO2();
        delay(100);
    }
    Serial.println("Sensor ready");
}

void reconnectWifi(void)
{
    WiFi.softAPdisconnect(true);
    static int n = 0;
    n = 0;
    WiFi.begin(ssid, password);

    while (WiFi.status() != WL_CONNECTED || n > 100)
    {
        delay(500);
        Serial.print(".");
        n++;
    }
    Serial.print("reconnected");
}

void getConfigFromPi()
{
    WiFiClientSecure httpsClient; //Declare object of class WiFiClient

    Serial.println(config_host);

    Serial.printf("Using fingerprint '%s'\n", fingerprint);
    httpsClient.setFingerprint(fingerprint);
    httpsClient.setTimeout(15000); // 15 Seconds
    delay(1000);

    Serial.print("HTTPS Connecting");
    int r = 0; //retry counter
    while ((!httpsClient.connect(config_host, 443)) && (r < 30))
    {
        delay(100);
        Serial.print(".");
        r++;
    }
    if (r == 30)
    {
        Serial.println("Connection failed");
    }
    else
    {
        Serial.println("Connected to web");
    }

    String ADCData, getData, Link;
    int adcvalue = analogRead(A0); //Read Analog value of LDR
    ADCData = String(adcvalue);    //String to interger conversion

    //GET Data
    uint8_t mac[6];
    WiFi.macAddress(mac);
    String mac_address = MacToString(mac);
    Link = "/api/v1.0/config/" + mac_address;

    Serial.print("requesting URL: ");
    Serial.println(config_host + Link);

    httpsClient.print(String("GET ") + Link + " HTTP/1.1\r\n" +
                      "Host: " + config_host + "\r\n" +
                      "Connection: close\r\n\r\n");

    Serial.println("request sent");

    String respond = "";

    while (httpsClient.connected())
    {
        String line = httpsClient.readStringUntil('\n');
        if (line == "\r")
        {
            Serial.println("headers received");
            break;
        }
    }

    Serial.println("reply was:");
    Serial.println("==========");
    String line;
    while (httpsClient.available())
    {
        line = httpsClient.readStringUntil('\n'); //Read Line by Line
        Serial.println(line);
        respond = respond + line; //Print response
    }
    Serial.println("==========");
    Serial.println("closing connection");

    int i = respond.indexOf('{');
    String json = respond.substring(i);

    Serial.println("JSON: ");
    Serial.println(json);

    StaticJsonDocument<1024> jsonDoc;
    auto parseError = deserializeJson(jsonDoc, json.c_str());

    if (parseError)
    {
        Serial.println("parseObject() failed: ");
        Serial.println(parseError.c_str());
        return;
    }

    arduinoConfig = new ArduinoConfig;
    arduinoConfig->location = jsonDoc["location"].as<String>();
    arduinoConfig->influx_bd_host = jsonDoc["influx_bd_host"].as<String>();
    arduinoConfig->room = jsonDoc["room"].as<String>();
    arduinoConfig->mac = jsonDoc["mac"].as<String>();
    arduinoConfig->sensor_type = jsonDoc["sensor_type"].as<String>();
    arduinoConfig->quality_port = jsonDoc["quality_port"];
    arduinoConfig->power_port = jsonDoc["power_port"];
    arduinoConfig->offset_temperature = jsonDoc["offset_temperature"];
    arduinoConfig->offset_humidity = jsonDoc["offset_humidity"];
}

void setup(void)
{
    /*-------------------Software Interupt-----------------------------------*/
    pinMode(D5, OUTPUT);
    digitalWrite(D5, HIGH);
    //-----------------------------------------------------------------------//
    //---------------------------Wifihotspo--from--ESP--disable---------------
    WiFi.softAPdisconnect(true);
    Wire.setClock(400000);
    Serial.begin(115200);
    delay(1000);

    // WiFi Connection -- START -----------------------------------------------
    WiFi.begin(ssid, password);

    while (WiFi.status() != WL_CONNECTED)
    {
        delay(500);
        Serial.print(".");
    }
    Serial.println("Wifi Connected to " + String(ssid));
    // WiFi Connection -- END -------------------------------------------------

    getConfigFromPi();

    // WiFi Mac Address Mapping -- START --------------------------------------
    String mac_address = arduinoConfig->mac;

    Serial.println("\n----- IMPORTANT INFORMATION -----");
    Serial.println(arduinoConfig->mac);
    Serial.println(arduinoConfig->location);
    Serial.println(arduinoConfig->room);
    Serial.println("---------------------------------\n");

    if (arduinoConfig->sensor_type == "power")
    {
        isPowerType = 1;
        isQualityType = 0;
        Serial.println("power");
        Powerflag = 1;

        dataPower.addTag("location", arduinoConfig->location);
        dataPower.addTag("room", arduinoConfig->room);
    }
    else
    {
        isPowerType = 0;
        isQualityType = 1;

        dataAirQuality.addTag("location", arduinoConfig->location);
        dataAirQuality.addTag("room", arduinoConfig->room);
    }
    // WiFi Mac Address Mapping -- END ----------------------------------------

    // Sensor Initialisation -- START -----------------------------------------
    if (isQualityType)
    {
        Si7021.begin();
        CCS811.begin();

        if (!CCS811.begin())
        {
            Serial.println("Failed to start CCS811! Please check your wiring.");
            while (!CCS811.available())
            {
                delay(200);
            }
        }
        else
        {
            Serial.println("CCS811 found");
        }
        while (!CCS811.available())
        {
            delay(200);
        }

        float temp;
        temp = CCS811.calculateTemperature();
        CCS811.setTempOffset(temp - 25.0);
    }

    if (isPowerType)
    {
        ADC_1.setGain(GAIN_ONE);
        ADC_2.setGain(GAIN_ONE);

        ADC_1.begin();
        ADC_2.begin();
    }

    // Sensor Initialisation -- END -------------------------------------------

    //activate Ticker
    DB_Updater.attach(1, timerCallback);
}

void loop(void)
{
    if (WiFi.status() != WL_CONNECTED)
    {
        reconnectWifi();
    }

    if ((tickOccured == true) && (writeflag == 1))
    {
        writeflag = 0;
        tickOccured = false;

        InfluxDB_UDP influxPowerPort(udp, arduinoConfig->influx_bd_host, arduinoConfig->power_port);
        InfluxDB_UDP influxSensorPort(udp, arduinoConfig->influx_bd_host, arduinoConfig->quality_port);

        if (isQualityType)
        {
            dataAirQuality.clear(InfluxDB_Data::FIELD);
            dataAirQuality.addField("temperature_c", String(temperature + arduinoConfig->offset_temperature));
            dataAirQuality.addField("TVOC_ppb", String(TVOC));
            dataAirQuality.addField("eCO2_ppm", String(eCO2));
            dataAirQuality.addField("humidity_RH", String(humidity + arduinoConfig->offset_humidity));
            influxSensorPort.write(dataAirQuality);
        }

        if (isPowerType)
        {
            Serial.println(power_1);
            Serial.println(power_3);
            Serial.println(power_2);
            dataPower.clear(InfluxDB_Data::FIELD);
            dataPower.addField("power1_W", String(power_1));
            dataPower.addField("power2_W", String(power_2));
            dataPower.addField("power3_W", String(power_3));
            dataPower.addField("powerTotal_W", String(power_total));
            influxPowerPort.write(dataPower);
        }
    }
    if (isQualityType)
    {
        LongRST++;
        delay(100);
        if (LongRST >= 12000)
        {
            LongRST = 0;
            SWI();
            humidity = Si7021.getRH();
            temperature = Si7021.getTemp();
            if (CCS811.available())
            {
                if (!CCS811.readData())
                {
                    eCO2OLD = eCO2;
                    TVOCOLD = TVOC;
                    eCO2 = CCS811.geteCO2();
                    TVOC = CCS811.getTVOC();
                }
                else
                {
                    Serial.println("ERROR!");
                }
            }
            if (eCO2 - eCO2OLD >= 20)
            {
                writeflag = 0;
                SWI();
            }
            else
            {
                writeflag = 1;
            }
        }
        humidity = Si7021.getRH();
        temperature = Si7021.getTemp();
        if (CCS811.available())
        {
            if (!CCS811.readData())
            {
                eCO2OLD = eCO2;
                TVOCOLD = TVOC;
                eCO2 = CCS811.geteCO2();
                TVOC = CCS811.getTVOC();
            }
            else
            {
                Serial.println("ERROR!");
            }
        }
        if (eCO2 - eCO2OLD >= 50)
        {
            writeflag = 0;
            SWI();
        }
        else
        {
            writeflag = 1;
        }
    }
    // current_coil = ((voltage_adc_1) * MAX_CURRENT_COIL)/MAX_VOLTAGE_ADC;
    //power = current_coil * COIL_WINDING * VOLTAGE_MAINS;

    if (isPowerType)
    {
        voltage_adc_1 = (calcVrms(32, 1)) / 1000.0;
        voltage_adc_2 = (calcVrms(32, 2)) / 1000.0;
        voltage_adc_3 = (calcVrms(32, 3)) / 1000.0;

        power_1 = calcPower(voltage_adc_1);
        power_2 = calcPower(voltage_adc_2);
        power_3 = calcPower(voltage_adc_3);
        power_total = power_1 + power_2 + power_3;
    }
}

double calcVrms(unsigned int Samples, unsigned int phase)
{
    float voltage_rms;
    float squared_voltage;
    float sample_voltage_sum;
    float sample_voltage;

    for (unsigned int n = 0; n < Samples; n++)
    {
        switch (phase)
        {
        case 1:
        {
            sample_voltage = ADC_1.readADC_Differential_0_1();
            break;
        }
        case 2:
        {
            sample_voltage = ADC_2.readADC_Differential_2_3();
            break;
        }
        case 3:
        {
            sample_voltage = ADC_2.readADC_Differential_0_1();
            break;
        }
        default:
            break;
        }
        squared_voltage = sample_voltage * sample_voltage;
        sample_voltage_sum += squared_voltage;
    }

    voltage_rms = (sqrt(sample_voltage_sum / Samples) * SCALEFACTOR) * sqrt(2);
    sample_voltage_sum = 0;
    return voltage_rms;
}

double calcPower(float voltage)
{
    double power;
    power = voltage / BURDEN_RESISTOR * COIL_WINDING * VOLTAGE_MAINS;
    return power;
}

String MacToString(const uint8_t *mac)
{
    String s_mac = "";
    for (int8_t index = 5; index >= 0; index--)
    {
        s_mac += String(mac[index], HEX);
        if (index != 0)
        {
            s_mac += ":";
        }
    }
    return s_mac;
}

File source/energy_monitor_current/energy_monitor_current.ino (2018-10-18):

#include <Wire.h>
#include <Adafruit_ADS1015.h>
#include <string.h>
#include <math.h>
#include <ESP8266WiFi.h>
#include <WiFiUdp.h>
#include <Ticker.h>

//---------------------------------------------------------------------------------------
#define INFLUXDB_HOST "10.1.0.230"
#define INFLUXDB_PORT_POWER 6969
#define INFLUXDB_PORT_SENSOR 6970


#define INFLUXDB_DATABASE "test"

#define INFLUXDB_LOCATION "coderbunker"
#define INFLUXDB_ROOM     "threephase"

const char* ssid     = "Agora Space";
const char* password = "getstuffdone";

Ticker tick;

bool tickOccured;


void timerCallback() {

      tickOccured = true;

}

void user_init(void)
{
    tick.attach(0.2, timerCallback);
}


WiFiUDP             udp;

Adafruit_ADS1115    ads(0x49);  // Declare an instance of the ADS1115

//int16_t rawADCvalue;  // The is where we store the value we receive from the ADS1115
float SCALEFACTOR = 0.125F; // This is the scale factor for the default +/- 4.096V Range we will use - see ADS1X15 Library
float MAX_CURRENT_COIL = 0.0707; // Maximum current of sensor rated at  Rms 100 A 
float MAX_VOLTAGE_ADC = 15.981; // Maximum Voltage on burden resistor calculated by burden resistor * maxAmps (33 Ohm * 0.0707 A)
float voltage_adc = 0.0; // The result of applying the scale factor to the raw value
float VOLTAGE_MAINS = 220.00; // line voltage
float current_coil = 0.0; // Calculated depending on the Voltage/Burden resistor 
float power;
float COIL_WINDING= 2000; // ratio of sensor 100:0.05

float sqV;
float sumV;
float sampleV;
float Vrms;

String line;
String PowerAsString;

void setup(void)
{
    Wire.setClock(400000);
    Serial.begin(115200); 
    delay(250);
    
    // * Connecting to specified WiFi
    WiFi.begin(ssid, password);

    //WiFi.getNetworkInfo();
    
    while (WiFi.status() != WL_CONNECTED) {
        delay(500);
        Serial.print(".");
    }

    Serial.println("Wifi Connected to" + String(ssid));
    // * WiFi connection FIN

    ads.setGain(GAIN_ONE);  
    
    ads.begin();
    user_init();

}

void loop(void)
{
    if(tickOccured)
    {
        tickOccured = false;

        String line = ("power_watt,location=" + String(INFLUXDB_LOCATION) + ",room=" + String(INFLUXDB_ROOM) +" value=" + String(power));

        String line = ("air_quality,location=" + ",room=" +",daniel=dumm"+ " temperature_c=xy,co2_ppm=xy,");

        //Prepare Value-Package & Send it off to the Database
        Serial.println(line);
        udp.beginPacket(INFLUXDB_HOST,INFLUXDB_PORT);

        udp.print(line);
        udp.endPacket();
    }
    voltage_adc = (calcVrms(32) )/1000.0;
    
    current_coil = ((voltage_adc) * MAX_CURRENT_COIL)/MAX_VOLTAGE_ADC;
    power = current_coil * COIL_WINDING * VOLTAGE_MAINS;

    
}

double calcVrms(unsigned int Number_of_Samples)
{
  
    for (unsigned int n = 0; n < Number_of_Samples; n++)
    {
        sampleV = ads.readADC_Differential_0_1();
        sqV = sampleV * sampleV;
        sumV += sqV;
    }
    
    Vrms = (sqrt(sumV / Number_of_Samples) * SCALEFACTOR) * sqrt(2);
    sumV = 0;    
    return Vrms;
}

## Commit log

2018-02-20 Added different sample rates for testing
2019-10-04 Fix sensor drift
2019-10-04 Create BOM Suppernanny.xlsx
    [BOM Suppernanny.xlsx]
2019-10-08 optimized the reset algorithm
    [Writing_Database.ino]
2019-10-11 Fix code after compilation
    [Writing_Database.ino]
2019-10-14 Fix get MAC address
    [Writing_Database.ino]
2019-10-14 Fix C++ Arduino language barrier
    [Writing_Database.ino]
2019-10-14 Test prints
2019-10-14 Fix get response endless loop
    [Writing_Database.ino]
2019-10-15 Fix implementation for GET from API
    [Writing_Database.ino]
2019-10-16 Added PCB Files
    [AT long bus (13.3 x 4.2 inches).GBL, AT long bus (13.3 x 4.2 inches).GBO, AT long bus (13.3 x 4.2 inches).GBP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]
2019-10-17 Revert "improve reset algorithm"
    This reverts commit 7ed969778a1ac12944d31947b8eb1bbaaf44fd4f.
    [Writing_Database.ino]
